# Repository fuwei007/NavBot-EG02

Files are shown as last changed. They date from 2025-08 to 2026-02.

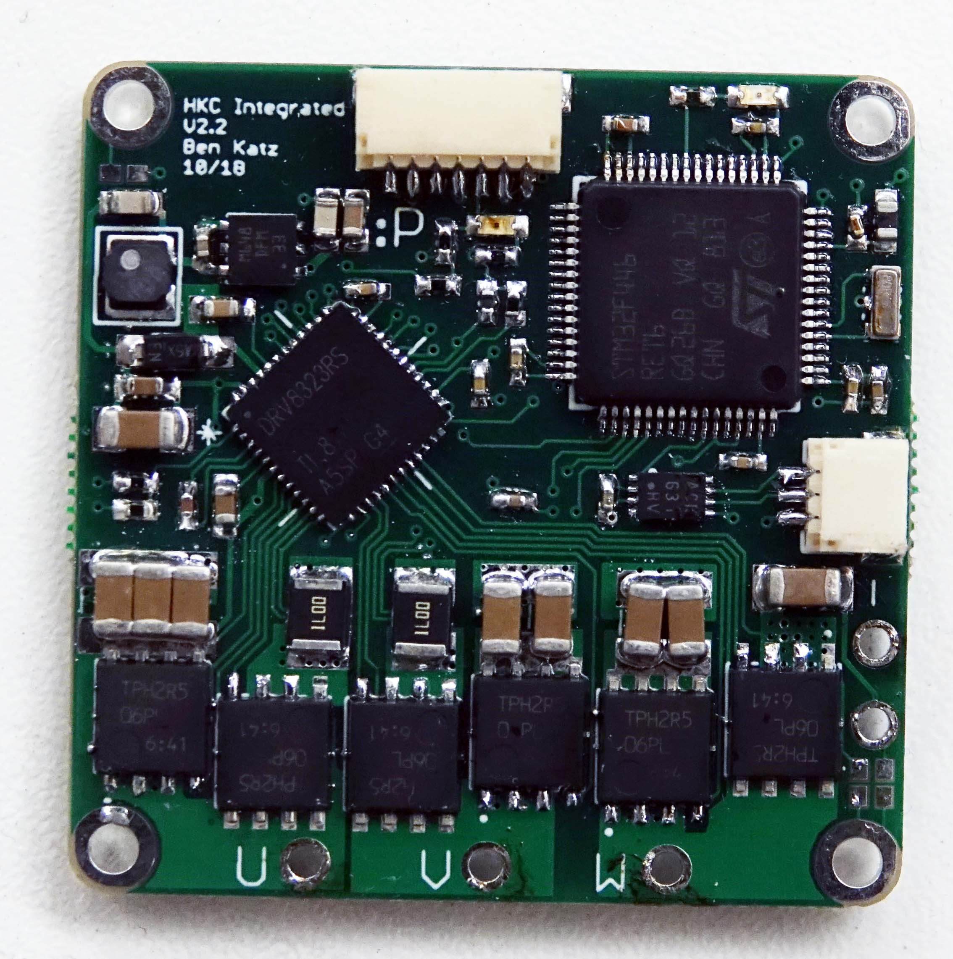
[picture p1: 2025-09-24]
2-Hardware/3phase_integrated-master/New Version/Cheetah Driver Integrated V4 connector/photos/DSC01706.JPG

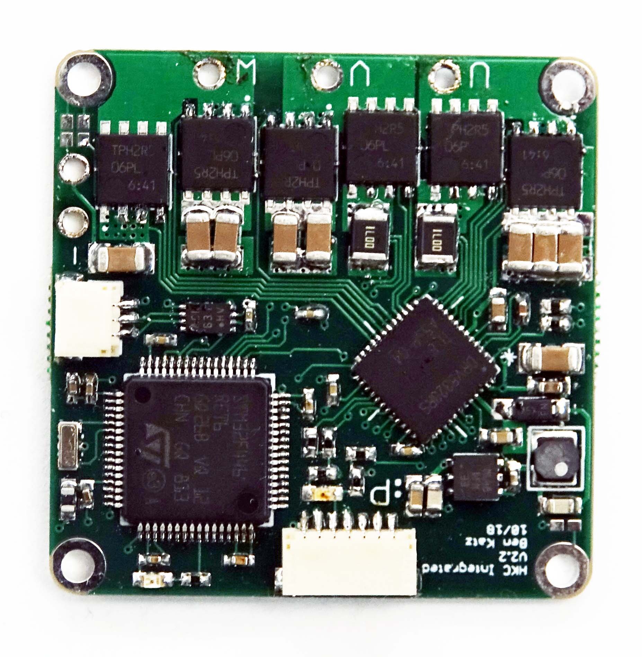
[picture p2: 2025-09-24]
2-Hardware/3phase_integrated-master/New Version/Cheetah Driver Integrated V4 connector/photos/DSC01701.JPG

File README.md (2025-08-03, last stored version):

# Mini Cheetah Single Leg Dev Kit (EG02)

This repository contains all open-source hardware and software resources to replicate and extend a **single leg of the MIT Mini Cheetah** robot. The goal is to provide a modular, low-cost, and extensible robotic leg development kit.

## ✅ Project Highlights
- Jetson Orin Nano 8GB as main controller
- MN5212 BLDC motor + NEMA 23 planetary gearbox + AS5047P magnetic encoder
- FSESC6.7 70A single-channel VESC motor driver
- Open-source mechanical parts (encoder mount, couplers) and ROS2-compatible design

## 📦 Current Progress
- [x] Hardware sourcing ✅
- [x] Encoder mount printed ✅
- [ ] Wiring & configuration in progress 🔧
- [ ] Jetson control code WIP 💻
- [ ] Quadruped-ready architecture in design 🐾

## 📁 Folder Structure
- `/hardware/` 3D models, CAD drawings, and mechanical designs
- `/jetson_control/` Jetson-side control scripts and ROS2 nodes
- `/docs/` BOM, wiring diagrams, setup notes
- `/config/` VESC settings, encoder calibration files

## 📷 Project Images
(To be added in `/images/`)

## 📜 License
MIT License

---
Project initiated by **NavBot LLC**. Contributions welcome!

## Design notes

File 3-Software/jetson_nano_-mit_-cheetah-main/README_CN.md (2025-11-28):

# MIT Mini Cheetah Software (自制硬件适配版)

本项目是 MIT Mini Cheetah 软件仓库的自制硬件适配版本。以下文档记录了编译、配置及针对自制硬件（Wheeltec IMU、自制腿部结构、Logitech F710 手柄）的详细调试与适配过程。

## 1. 编译与运行指南

### 1.1 命令行编译
建议在项目根目录下的 `mc-build` 文件夹中进行构建。

```bash
cd mc-build
rm CMakeCache.txt  # 清理旧配置（如有必要）

# 配置项目
# -DMINI_CHEETAH_BUILD=TRUE: 构建 Mini Cheetah 版本
# -DJCQP_USE_AVX2=OFF: 关闭 x86 AVX2 优化，适配 ARM 架构（如 Jetson Nano/NX）
cmake -DMINI_CHEETAH_BUILD=TRUE -DJCQP_USE_AVX2=OFF ..

# 编译（根据 CPU 核心数调整 -j 参数）
make -j4
```

### 1.2 运行控制器
生成的控制器位于 `user/MIT_Controller` 目录下。需要使用 `sudo` 权限运行以访问硬件端口。

*   **真机模式**：
    ```bash
    sudo ./user/MIT_Controller/mit_ctrl m r f
    ```
*   **仿真模式**：
    ```bash
    sudo ./user/MIT_Controller/mit_ctrl m s
    ```

---

## 2. 开发环境配置 (VSCode Remote - SSH)

推荐使用 VSCode 进行远程开发与调试。

1.  本机安装 **Remote - SSH** 与 **CMake Tools** 扩展。
2.  通过 Remote-SSH 连接到目标主机（如 Jetson），打开项目目录。
3.  项目已预置 `.vscode/settings.json`，自动配置构建参数。
4.  **首次使用**：
    *   按 `F1` 或 `Ctrl+Shift+P`，输入 `CMake: Select Kit`，选择远程环境的编译器（如 `GCC for arm64`）。
    *   确保 `mc-build` 目录存在。
5.  **一键编译**：
    *   点击 VSCode 底部状态栏的 **Build** 按钮即可触发远程编译。
    *   如需清理缓存，使用命令 `CMake: Delete Cache and Reconfigure`。

**`.vscode/settings.json` 参考配置：**
```jsonc
{
  "cmake.buildDirectory": "${workspaceFolder}/mc-build",
  "cmake.generator": "Unix Makefiles",
  "cmake.configureArgs": [
    "-DMINI_CHEETAH_BUILD=TRUE",
    "-DJCQP_USE_AVX2=OFF"
  ],
  "cmake.buildArgs": [
    "-j4"
  ]
}
```

---

## 3. 硬件配置说明

*   **IMU**: 默认适配 **Wheeltec H30** 惯导模块。
    *   可通过环境变量调整串口：
        *   `H30_IMU_PORT` (默认 `/dev/ttyACM0`)
        *   `H30_IMU_BAUD` (默认 `460800`)
*   **遥控器**: 适配 **Logitech F710** 无线手柄。
    *   手柄必须拨至 **D (DirectInput)** 模式。
    *   默认设备路径：`/dev/input/js0` (可通过 `F710_DEVICE` 环境变量修改)。
    *   程序强制 `use_rc=0`，无需连接 SBUS 接收机。

---

## 4. 自制硬件适配与调试记录 (2025-11)

### 4.1 核心问题解决：自旋与侧翻
在调试初期，机器人进入 `BalanceStand` 后会出现剧烈的自旋（Yaw 轴）或侧翻（Roll 轴）。

*   **原因**：Wheeltec H30 IMU 的 Roll/Pitch/Yaw 三轴数据方向与 MIT 控制器预期**完全相反**。导致控制器输出的正反馈力矩加剧了失稳。
    *   现象：左转 Yaw 减小（应增加），右倾 Roll 减小（应增加），抬头 Pitch 增加（MIT 定义低头为正）。
*   **修复**：修改 `third-party/wheeltec_imu/WheeltecImu.cpp` 中的 `handlePacket` 函数。
    *   **操作**：将四元数转换为 RPY 欧拉角，**对 Roll, Pitch, Yaw 三轴全部取反**，再转回四元数。
    *   **结果**：姿态估计正确，`BalanceStand` 立即稳定。

### 4.2 动力学模型修正
*   **文件**：`common/include/Dynamics/MiniCheetah.h`
*   **腿部惯量**：自制腿部较重。尝试过放大惯量 (`inertia_scale = 2.0`)，但导致控制过激。最终**回调至 1.0** (MIT 原版参数)，配合增益调整效果最佳。
*   **机身惯量**：将人为放大的 `bodyRotationalInertia` 从 3.0 倍回调至 **1.5 倍**，使模型更接近物理真实。

### 4.3 底层驱动校准
*   **文件**：`robot/src/rt/rt_spi.cpp`
*   **电机零位**：硬编码的 `abad/hip/knee_offset` 是底层物理零位，必须严格对应电机编码器的几何零点。
*   **电机方向**：验证了 `*_side_sign` 数组。确认左后腿 (Leg 3) Abad 向外摆动时读数增加（正），符合 MIT 定义。

### 4.4 控制参数调优
*   **文件**：`config/mc-mit-ctrl-user-parameters.yaml`
*   **解决“趴得低”**：
    *   增加 Z 轴位置刚度 `Kp_body[2]`：从 60 提高到 **100**。
*   **解决“Hip 软 / 前后晃”**：
    *   增加关节位置刚度 `Kp_joint`：从 `[6, 6, 6]` 调整为 **`[6, 8, 8]`** (Abad, Hip, Knee)。
    *   增加关节阻尼 `Kd_joint`：从 `[0.4, 0.4, 0.4]` 调整为 **`[0.4, 0.8, 0.8]`**。
*   **解决“劈叉”**：
    *   主要依赖增加 Abad 关节刚度（如上所述）。
    *   如有需要，可降低 `RPC_mu` (摩擦系数) 来限制侧向力。

### 4.5 手柄控制功能实现
MIT 原始代码未将 Gamepad 数据映射到核心控制指令 `rcCommand`，导致手柄摇杆无效。

*   **修复**：在 `robot/src/RobotRunner.cpp` 的 `run()` 函数中（`setupStep()` 调用**之后**）添加映射逻辑。
*   **映射关系 (符合 MIT 习惯)**：
    *   **右摇杆**：控制 Roll (左右倾斜) / Pitch (前后倾斜)。
    *   **左摇杆**：控制 Yaw (转向，需取反 `-LX`) / Height (高度升降)。
*   **灵敏度**：设置缩放系数 `kScaleRPY = 0.35`, `kScaleH = 0.4`，手感柔和。
*   **控制模式**：`FSM_State_BalanceStand.cpp` 修改为**松手自动回中**（比例控制），松开摇杆后机器人自动恢复水平和初始高度。

### 4.6 遗留风险提示
*   **Locomotion (原地踏步)**：**极高风险！**
    *   目前的接触估计器 (`ContactEstimator`) 是基于步态计划的盲信逻辑，不依赖真实触地反馈。
    *   **未验证项**：IMU 的线性加速度 (Acc) 方向尚未经过严格验证（虽然 RPY 已修）。如果 Acc 方向也是反的，卡尔曼滤波会瞬间发散导致炸机。
    *   **建议**：在严格验证 Acc 方向（前推 AccX 为正，静止 Z 为 +9.8）之前，**严禁尝试 Trot 步态**。

---

## 常用 Git 命令速查

### 本地操作
*   **补充提交**（修改上一次 commit）：
    ```bash
    git commit --amend --no-edit
    ```
*   **强制推送**（覆盖远端）：
    ```bash
    git push --force-with-lease
    ```

### 远程同步
*   **强制重置到远端 main**（丢弃本地所有修改）：
    ```bash
    git fetch origin && git reset --hard origin/main && git clean -fd
    ```
    *   `git fetch origin`: 获取最新元数据
    *   `git reset --hard origin/main`: 强制移动指针并重置工作区
    *   `git clean -fd`: 删除未跟踪的文件和目录

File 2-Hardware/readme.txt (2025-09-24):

主要是电路板和底层软件： MIT Cheetah Mini 电机驱动器, 连接12个电机与机载电脑的中心板(SPIne)的代码和硬件

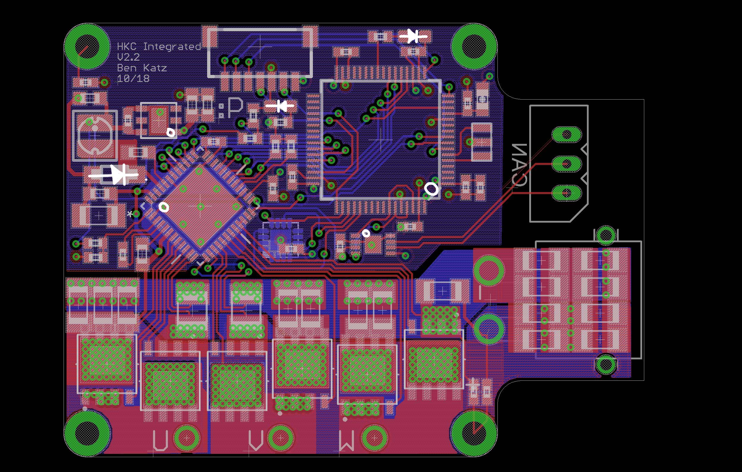
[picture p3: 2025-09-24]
2-Hardware/3phase_integrated-master/New Version/Cheetah Driver Integrated V4 connector/board.JPG

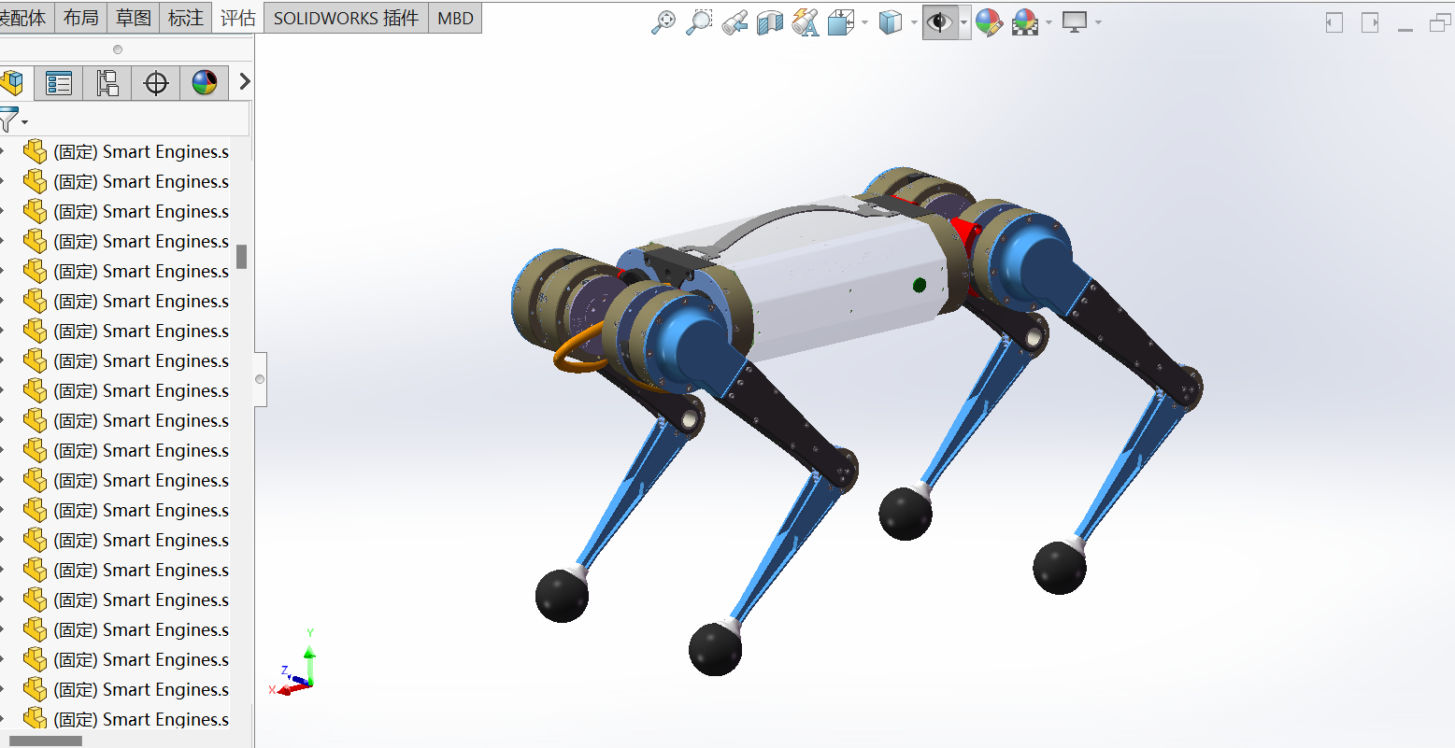
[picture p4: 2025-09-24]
1-3D Files/sw.png

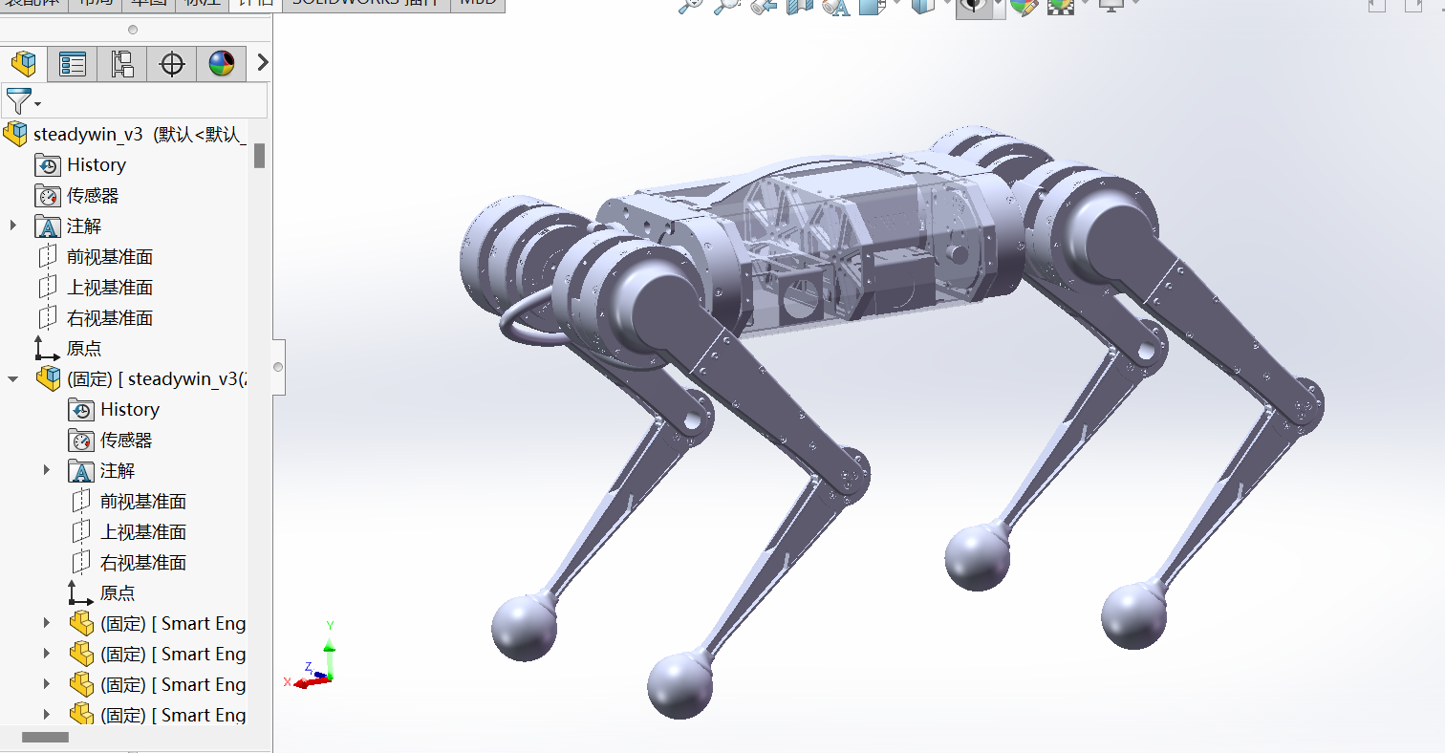
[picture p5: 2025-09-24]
1-3D Files/structure.png

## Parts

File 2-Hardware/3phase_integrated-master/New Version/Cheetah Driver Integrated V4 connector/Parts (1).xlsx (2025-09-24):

Supplied Parts
Qty Per Board | Value | Device | Package | Parts | MFG Part | 56
1 | DRV8323RH | DRV8323RH | QFN50P700X700X90-49N | U$1 | ‎DRV8323RSRGZT‎
2 | G | LED0603 | LED-0603 | LED1, LED2 | LTST-C191KRKT‎
1 | 3.3V 500 mA LDO | LDFM | DFN6-3X3 | LDFM33PUR | ‎LDFM33PUR‎
1 | MA700 | MA700 | QFN16 | U$11 | ‎MA700GQ-Z‎
1 | MCP2542 | MCP2542 | TDFN | U$6 | ‎MCP2542FDT-H/MNY‎
1 | SM07B-SRSS-TB | SM07B-SRSS-TB | SM07B-SRSS-TB | PROG | ‎SM07B-SRSS-TB(LF)(SN)‎
1 | STM32F446RET6 | STM32F446RET6 | TQFP64 | U$3 | ‎STM32F446RET6‎
6 | 60V | MOSFET | Power SO8 | Q1, Q2, Q3, Q4, Q5, Q6 | ‎TPH2R506PL,L1Q‎
9 | 10 uF 50v | C-USC1206K | C1206K | C1, C8, C11, C12, C13, C14, C15, C16, C17, C21, C22, C23, C24, C25, C26, C28, C29 | GRT31CR61H106ME01L
1 | 22uH 500 mA | SDR0302 | SDR0302 | L1 | ‎NRH3012T220MN‎
2 | 0.001 | R-US_R1210 | R1210 | R6, R7 | ‎PMR25HZPFV1L00‎
1 | 600r | INDUCTOR0603 | 603 | CHOKE | ‎PE-0603FB601ST‎
1 | 8 Mhz Ceramic Resonator | CSTCE | CSTCE | XT1 | ‎CSTNE8M00GH5L000R0‎
1 | 500 mA 60v | DIODE-SOD123 | SOD123 | D1 | ‎MBR0580S1-7‎
8 | .1 uF 10v X5R/X7R | C-USC0402K | C0402K | C18, C27, C31, C32, C33, C34, C41, VREFCAP | ‎CL05A104MP5NNNC
2 | .1 uF 50v X5R/X7R | C-USC0603K | C0603K | C2, C4 | ‎CC0603JRX7R9BB104‎
3 | 1 uF 10v X5R/X7R | C-USC0402K | C0402K | C7, C10, MC1 | ‎CL05A105MP5NNNC‎
1 | 1 uF 50v X5R/X7R | C-USC0603K | C0603K | C6 | ‎CL10A105KB8NNNC‎
4 | 10k 1% | R-US_R0402 | R0402 | R2, R3, R4 R27 | ‎RT0402DRE0710KL‎
1 | 150k 1% | R-US_R0402 | R0402 | R26 | ‎RMCF0402FT150K‎
2 | 200 5% | R-US_R0402 | R0402 | R5, R22 | ‎RC0402JR-07200RL‎
3 | 22 uF 10v X5R/X7R | C-USC0603K | C0603K | C3, C19, C20 | ‎CL10A226MPCNUBE‎
1 | 4.7 uF 10v X5R/X7R | C-USC0402K | C0402K | C9 | ‎GRM155R60J475ME87D‎
1 | 47 nF 50v X5R/X7R | C-USC0402K | C0402K | C5 | ‎CGA2B3X7R1H473M050BD‎
1 | 54.9k 1% | R-US_R0402 | R0402 | R1 | ‎RC0402FR-0754K9L‎

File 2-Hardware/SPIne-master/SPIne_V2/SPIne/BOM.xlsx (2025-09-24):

Qty | Value | Package | Part | MFG Part Number | Digikey Number
1 |  | 43045-0400 | DC_IN | ‎0430450400‎ | ‎WM1814-ND‎
1 |  | MA20-1L | SV1 | ‎M20-7822046‎ | ‎952-1905-ND‎
4 | 120 | R0402 | R3, R5, R6, R7 | ‎CRGCQ0603F120R‎ | ‎A129677CT-ND‎
1 | DNP | R0402 | BYP
20 | .1 uF | C0603K | C1, C8, C12, C14, C16, C18, C19, C20, C21, C22, C23, C24, C4, C5, C6, C25, C27, C29, C31, C32 | ‎C0603C104M5RACTU‎ | ‎399-7845-1-ND‎
8 | 1uF | C0603 | C7, C41, C11, C13, C15, C17, C3, C10 | ‎UMK107AB7105KA-T‎ | ‎587-3247-1-ND‎
1 | 10 uF | C0805K | C30 | ‎GRM188R61E106MA73D‎ | ‎490-7202-1-ND‎
2 | 4.7 uF | C0603 | C2, C9 | ‎CL10A475MQ8NNNC‎ | ‎1276-1907-1-ND‎
5 | 47 uF | C1206K | C28, C33, C34, C35, C36 | ‎GRM32EC81C476KE15K‎ | ‎490-16309-1-ND‎
2 | 600r | 603 | CHOKE, CHOKE1 | ‎PE-0603FB601ST‎ | ‎553-2384-1-ND‎
2 | 200 | R0603 | R4, R22 | ‎RC0603JR-07200RL‎ | ‎311-200GRCT-ND‎
1 | 74AHC1G14DCK | SC70-5 | IC1 | SN74AHC1G14DCKR | 296-8748-1-ND
2 | BM07B-SRSS-TB | BM07B-SRSS-TB | PROG, PROG1 | ‎BM07B-SRSS-TB(LF)(SN)‎ | ‎455-1793-1-ND‎
2 | CSTCE | CSTCE | XT1, XT2 | CSTNE8M00GH5C000R0‎ | ‎490-17961-1-ND‎
2 | LED_RED | LED-0603 | LED2, LED4 | ‎LTST-C191KRKT‎ | ‎160-1447-1-ND‎
1 | LM1117 | SOT-223 | VR1 | LM1117MPX-3.3/NOPB | LM1117MPX-3.3/NOPBCT-ND
4 | ‎MCP2562-E/SN‎ | SO08 | U$4, U$5, U$6, U$7 | ‎MCP2562-E/SN‎ | ‎MCP2562-E/SN-ND‎
4 | SI8621EC-B-IS | SO08 | U$8, U$9, U$10, U$11 | SI8621EC-B-IS | 336-2066-5-ND
2 | STM32F446RET6 | TQFP64 | U$1, U$3 | ‎STM32F446RET6‎ | ‎497-15376-ND‎
4 | ‎CRE1S0505S3C‎ | 4SIL | DC1, DC2, DC3, DC4 | ‎CRE1S0505S3C‎ | ‎811-3195-ND‎
4 | 17mm hex standoff |  |  | ‎971170151‎ | ‎732-10424-ND‎
4 | 11mm hex standoff |  |  | ‎M2106-2545-AL‎ | ‎1772-2024-ND‎
1 | 40 pin |  |  | SSQ-120-02-T-D | SAM1193-20-ND

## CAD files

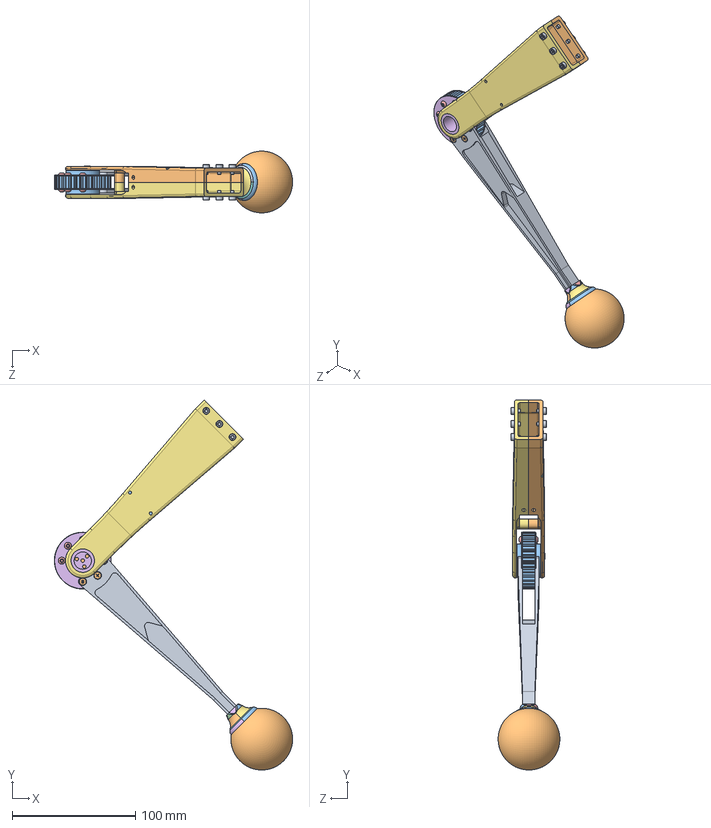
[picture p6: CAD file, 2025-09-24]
1-3D Files/sw2022/MIT-机器狗-腿部结构.SLDASM
193.0 x 299.7 x 50.0 mm
Smart Engines.sldasm-Part-32
Smart Engines.sldasm-Part-33
Smart Engines.sldasm-Part-34 x 15
Smart Engines.sldasm-Part-35
Smart Engines.sldasm-Part-36
Smart Engines.sldasm-Part-37
Smart Engines.sldasm-Part-38
Smart Engines.sldasm-Part-39
Smart Engines.sldasm-Part-40
Smart Engines.sldasm-Part-41
Smart Engines.sldasm-Part-42
Smart Engines.sldasm-Part-43
Smart Engines.sldasm-Part-44
Smart Engines.sldasm-Part-45
Smart Engines.sldasm-Part-46
Smart Engines.sldasm-Part-47
Smart Engines.sldasm-Part-48
Smart Engines.sldasm-Part-49
Smart Engines.sldasm-Part-50
Smart Engines.sldasm-Part-51
Smart Engines.sldasm-Part-52
Smart Engines.sldasm-Part-53
Smart Engines.sldasm-Part-54
Smart Engines.sldasm-Part-55
Smart Engines.sldasm-Part-56
Smart Engines.sldasm-Part-57
Smart Engines.sldasm-Part-58
Smart Engines.sldasm-Part-59
Smart Engines.sldasm-Part-60
Smart Engines.sldasm-Part-61
Smart Engines.sldasm-Part-62
Smart Engines.sldasm-Part-63
Smart Engines.sldasm-Part-64
Smart Engines.sldasm-Part-65
Smart Engines.sldasm-Part-66
Smart Engines.sldasm-Part-67
Smart Engines.sldasm-Part-68
Smart Engines.sldasm-Part-69
Smart Engines.sldasm-Part-70
Smart Engines.sldasm-Part-71
Smart Engines.sldasm-Part-72
Smart Engines.sldasm-Part-73
Smart Engines.sldasm-Part-74
Smart Engines.sldasm-Part-75
Smart Engines.sldasm-Part-76
Smart Engines.sldasm-Part-77
Smart Engines.sldasm-Part-78
Smart Engines.sldasm-Part-79
Smart Engines.sldasm-Part-80
Smart Engines.sldasm-Part-81
Smart Engines.sldasm-Part-82
Smart Engines.sldasm-Part-83
Smart Engines.sldasm-Part-84
Smart Engines.sldasm-Part-85
Smart Engines.sldasm-Part-86
Smart Engines.sldasm-Part-87
Smart Engines.sldasm-Part-88 x 6
Smart Engines.sldasm-Part-90 x 9
Smart Engines.sldasm-Part-91 x 2
Smart Engines.sldasm-Part-92 x 3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

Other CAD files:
1-3D Files/sw2022/Smart Engines.sldasm-Part-90.SLDPRT
1-3D Files/sw2022/Smart Engines.sldasm-Part-38.SLDPRT
1-3D Files/sw2022/Smart Engines.sldasm-Part-66.SLDPRT
1-3D Files/sw2022/Smart Engines.sldasm-Part-40.SLDPRT
1-3D Files/sw2022/Smart Engines.sldasm-Part-121.SLDPRT
1-3D Files/sw2022/Smart Engines.sldasm-Part-2.SLDPRT
1-3D Files/sw2022/Smart Engines.sldasm-Part-82.SLDPRT
1-3D Files/sw2022/Smart Engines.sldasm-Part-68.SLDPRT
1-3D Files/sw2022/Smart Engines.sldasm-Part-37.SLDPRT
1-3D Files/sw2022/Smart Engines.sldasm-Part-3.SLDPRT
1-3D Files/sw2022/Smart Engines.sldasm-Part-43.SLDPRT
1-3D Files/sw2022/Smart Engines.sldasm-Part-64.SLDPRT
1-3D Files/sw2022/Smart Engines.sldasm-Part-84.SLDPRT
1-3D Files/sw2022/Smart Engines.sldasm-Part-72.SLDPRT
1-3D Files/sw2022/Smart Engines.sldasm-Part-101.SLDPRT
1-3D Files/sw2022/Smart Engines.sldasm-Part-108.SLDPRT
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

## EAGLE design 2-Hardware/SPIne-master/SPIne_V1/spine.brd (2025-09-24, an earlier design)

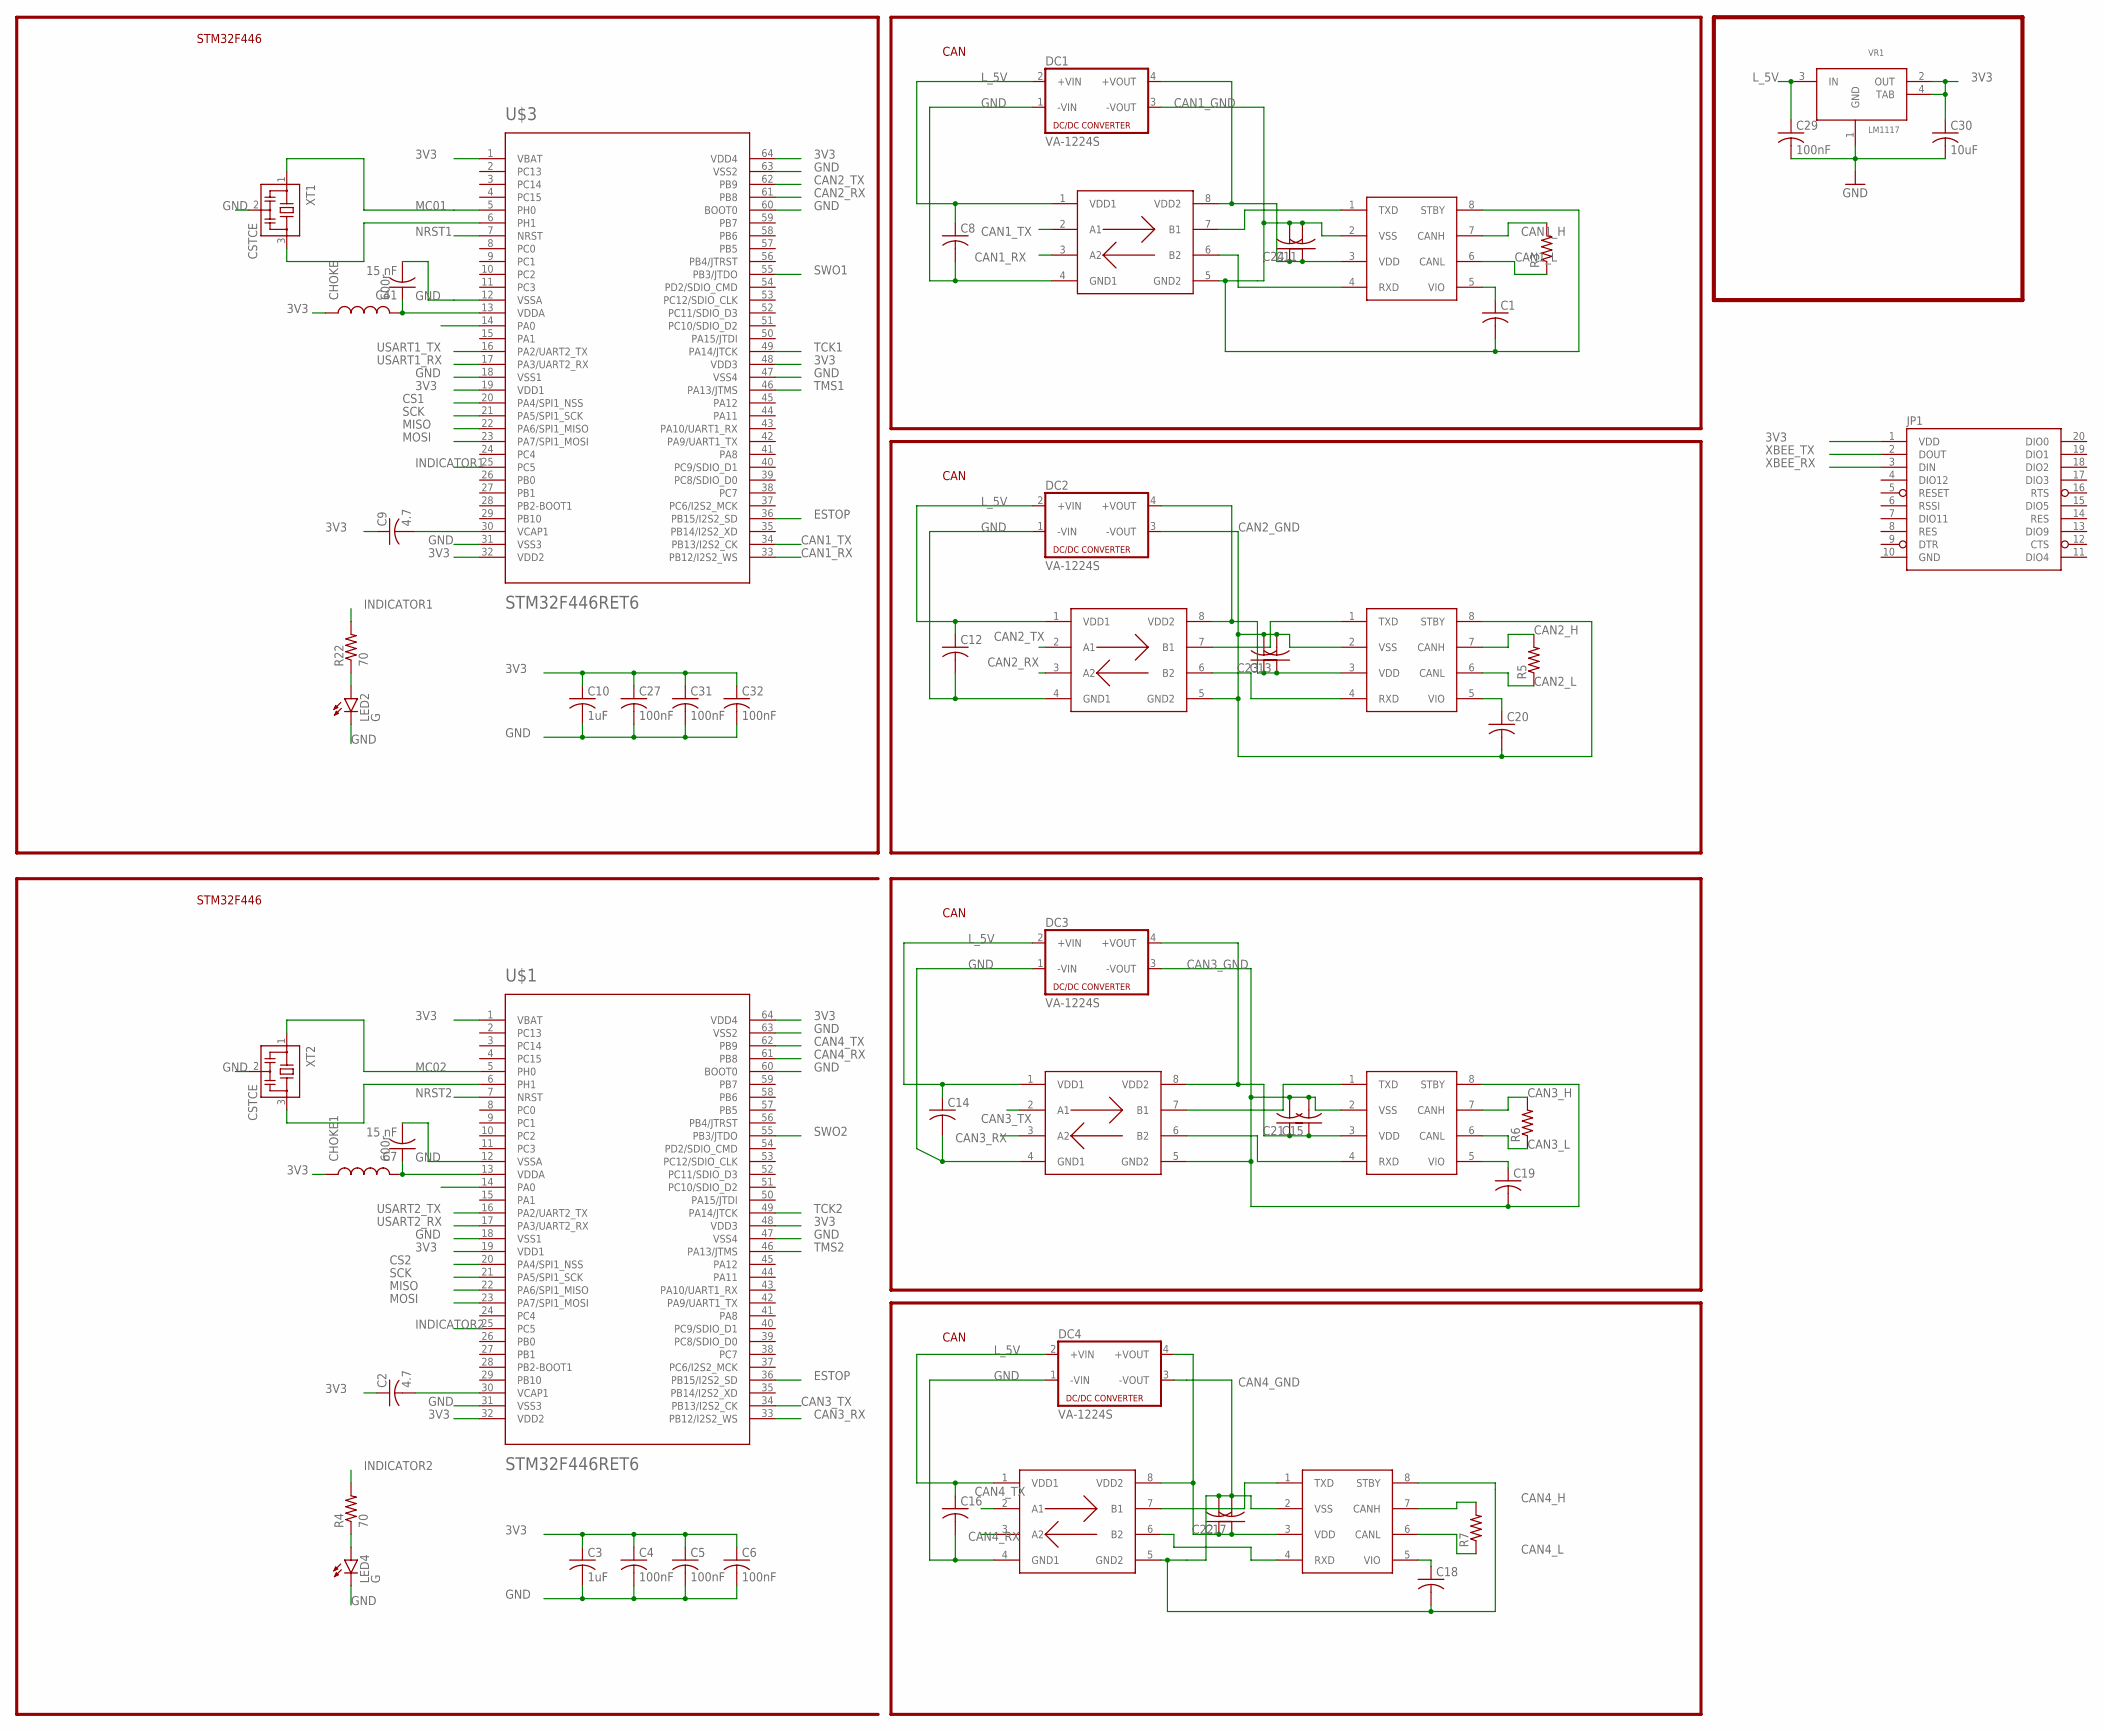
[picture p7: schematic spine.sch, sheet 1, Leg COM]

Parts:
C1, C8, C11, C12, C13, C14, C15, C16, C17, C18, C19, C20, C21, C22, C23, C24: C-USC0603K; C0603K
C2, C9: 4.7; C0603
C3, C10: 1uF; C0603
C4, C5, C6, C27, C29, C31, C32: 100nF; C0603
C7, C41: 15 nF; C0603
C30: 10uF; C0805K
CHOKE, CHOKE1: 600r; 0603
DC1, DC2, DC3, DC4: VA-1224S; 4SIL
JP1: XBEE-1B1; XBEE-1
LED2, LED4: G; LED-0603
R3, R5, R6, R7: R-US_R0603; R0603
R4, R22: 70; R0603
U$1, U$3: STM32F446RET6; TQFP64
U$4, U$5, U$6, U$7: MCP2561; SO08
U$8, U$9, U$10, U$11: SI8410; SO08
VR1: LM1117; SOT-223
XT1, XT2: CSTCE

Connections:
3V3: C2.1, C3.1, C4.1, C5.1, C6.1, C9.1, C10.1, C27.1, C30.1, C31.1, C32.1, CHOKE.1, CHOKE1.1, JP1.1 (VDD), U$1.1 (VBAT), U$1.19 (VDD1), U$1.32 (VDD2), U$1.48 (VDD3), U$1.64 (VDD4), U$3.1 (VBAT), U$3.19 (VDD1), U$3.32 (VDD2), U$3.48 (VDD3), U$3.64 (VDD4), VR1.2 (OUT), VR1.4 (TAB); also elsewhere on the board
CAN1_GND: C1.2, C11.2, C24.2, DC1.3 (-VOUT), U$4.2 (VSS), U$4.8 (STBY), U$8.5 (GND2); also elsewhere on the board
CAN1_H: R3.2, U$4.7 (CANH); also elsewhere on the board
CAN1_L: R3.1, U$4.6 (CANL); also elsewhere on the board
CAN1_RX: U$3.33 (PB12/I2S2_WS), U$8.3 (A2)
CAN1_TX: U$3.34 (PB13/I2S2_CK), U$8.2 (A1)
CAN2_GND: C13.2, C20.2, C23.2, DC2.3 (-VOUT), U$5.2 (VSS), U$5.8 (STBY), U$10.5 (GND2); also elsewhere on the board
CAN2_H: R5.2, U$5.7 (CANH); also elsewhere on the board
CAN2_L: R5.1, U$5.6 (CANL); also elsewhere on the board
CAN2_RX: U$3.61 (PB8), U$10.3 (A2)
CAN2_TX: U$3.62 (PB9), U$10.2 (A1)
CAN3_GND: C15.2, C19.2, C21.2, DC3.3 (-VOUT), U$6.2 (VSS), U$6.8 (STBY), U$9.5 (GND2); also elsewhere on the board
CAN3_H: R6.2, U$6.7 (CANH); also elsewhere on the board
CAN3_L: R6.1, U$6.6 (CANL); also elsewhere on the board
CAN3_RX: U$1.33 (PB12/I2S2_WS), U$9.3 (A2)
CAN3_TX: U$1.34 (PB13/I2S2_CK), U$9.2 (A1)
CAN4_GND: C17.2, C18.2, C22.2, DC4.3 (-VOUT), U$7.2 (VSS), U$7.8 (STBY), U$11.5 (GND2); also elsewhere on the board
CAN4_H: R7.2, U$7.7 (CANH); also elsewhere on the board
CAN4_L: R7.1, U$7.6 (CANL); also elsewhere on the board
CAN4_RX: U$1.61 (PB8), U$11.3 (A2)
CAN4_TX: U$1.62 (PB9), U$11.2 (A1)
CS1: U$3.20 (PA4/SPI1_NSS); also elsewhere on the board
CS2: U$1.20 (PA4/SPI1_NSS); also elsewhere on the board
ESTOP: U$1.36 (PB15/I2S2_SD), U$3.36 (PB15/I2S2_SD); also elsewhere on the board
GND: C3.2, C4.2, C5.2, C6.2, C7.2, C8.2, C10.2, C12.2, C14.2, C16.2, C27.2, C29.2, C30.2, C31.2, C32.2, C41.2, DC1.1 (-VIN), DC2.1 (-VIN), DC3.1 (-VIN), DC4.1 (-VIN), JP1.10 (GND), LED2.C, LED4.C, U$1.12 (VSSA), U$1.18 (VSS1), U$1.31 (VSS3), U$1.47 (VSS4), U$1.60 (BOOT0), U$1.63 (VSS2), U$3.12 (VSSA), U$3.18 (VSS1), U$3.31 (VSS3), U$3.47 (VSS4), U$3.60 (BOOT0), U$3.63 (VSS2), U$8.4 (GND1), U$9.4 (GND1), U$10.4 (GND1), U$11.4 (GND1), VR1.1 (GND), XT1.2, XT2.2; also elsewhere on the board
INDICATOR1: R22.2, U$3.25 (PC5)
INDICATOR2: R4.2, U$1.25 (PC5)
L_5V: C8.1, C12.1, C14.1, C16.1, C29.1, DC1.2 (+VIN), DC2.2 (+VIN), DC3.2 (+VIN), DC4.2 (+VIN), U$8.1 (VDD1), U$9.1 (VDD1), U$10.1 (VDD1), U$11.1 (VDD1), VR1.3 (IN); also elsewhere on the board
MC01: U$3.5 (PH0), XT1.1
MC02: U$1.5 (PH0), XT2.1
MISO: U$1.22 (PA6/SPI1_MISO), U$3.22 (PA6/SPI1_MISO); also elsewhere on the board
MOSI: U$1.23 (PA7/SPI1_MOSI), U$3.23 (PA7/SPI1_MOSI); also elsewhere on the board
unnamed: C41.1, CHOKE.2, U$3.13 (VDDA)
unnamed: C9.2, U$3.30 (VCAP1)
unnamed: C7.1, CHOKE1.2, U$1.13 (VDDA)
unnamed: C2.2, U$1.30 (VCAP1)
unnamed: C1.1, U$4.5 (VIO)
unnamed: LED4.A, R4.1
unnamed: U$1.6 (PH1), XT2.3
unnamed: C17.1, C22.1, DC4.4 (+VOUT), U$7.3 (VDD), U$11.8 (VDD2)
unnamed: C20.1, U$5.5 (VIO)
unnamed: C15.1, C21.1, DC3.4 (+VOUT), U$6.3 (VDD), U$9.8 (VDD2)
unnamed: C11.1, C24.1, DC1.4 (+VOUT), U$4.3 (VDD), U$8.8 (VDD2)
unnamed: U$4.1 (TXD), U$8.7 (B1)
unnamed: U$7.1 (TXD), U$11.7 (B1)
unnamed: U$4.4 (RXD), U$8.6 (B2)
unnamed: U$7.4 (RXD), U$11.6 (B2)
unnamed: C18.1, U$7.5 (VIO)
unnamed: C13.1, C23.1, DC2.4 (+VOUT), U$5.3 (VDD), U$10.8 (VDD2)
unnamed: U$5.1 (TXD), U$10.7 (B1)
unnamed: U$5.4 (RXD), U$10.6 (B2)
unnamed: C19.1, U$6.5 (VIO)
unnamed: U$6.1 (TXD), U$9.7 (B1)
unnamed: U$6.4 (RXD), U$9.6 (B2)
unnamed: LED2.A, R22.1
unnamed: U$3.6 (PH1), XT1.3
NRST1: U$3.7 (NRST); also elsewhere on the board
NRST2: U$1.7 (NRST); also elsewhere on the board
SCK: U$1.21 (PA5/SPI1_SCK), U$3.21 (PA5/SPI1_SCK); also elsewhere on the board
SWO1: U$3.55 (PB3/JTDO); also elsewhere on the board
SWO2: U$1.55 (PB3/JTDO); also elsewhere on the board
TCK1: U$3.49 (PA14/JTCK); also elsewhere on the board
TCK2: U$1.49 (PA14/JTCK); also elsewhere on the board
TMS1: U$3.46 (PA13/JTMS); also elsewhere on the board
TMS2: U$1.46 (PA13/JTMS); also elsewhere on the board
USART1_RX: U$3.17 (PA3/UART2_RX); also elsewhere on the board
USART1_TX: U$3.16 (PA2/UART2_TX); also elsewhere on the board
USART2_RX: U$1.17 (PA3/UART2_RX); also elsewhere on the board
USART2_TX: U$1.16 (PA2/UART2_TX); also elsewhere on the board
XBEE_RX: JP1.3 (DIN); also elsewhere on the board
XBEE_TX: JP1.2 (DOUT); also elsewhere on the board

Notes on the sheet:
STM32F446
CAN

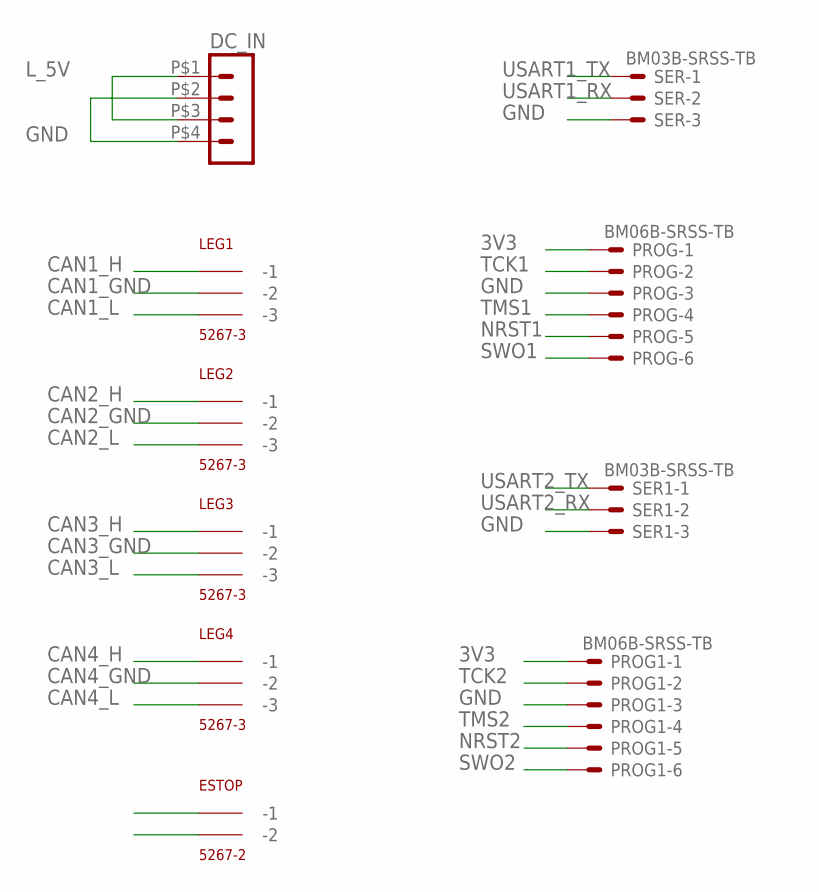
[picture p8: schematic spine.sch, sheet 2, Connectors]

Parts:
DC_IN: HEADER_POS4_43045-0401; 43045-0400
ESTOP: 5267-2
LEG1, LEG2, LEG3, LEG4: 5267-3
PROG, PROG1: BM06B-SRSS-TB
SER, SER1: BM03B-SRSS-TB

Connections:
3V3: PROG.1, PROG1.1; also elsewhere on the board
CAN1_GND: LEG1.P$2 (-2); also elsewhere on the board
CAN1_H: LEG1.P$1 (-1); also elsewhere on the board
CAN1_L: LEG1.P$3 (-3); also elsewhere on the board
CAN2_GND: LEG2.P$2 (-2); also elsewhere on the board
CAN2_H: LEG2.P$1 (-1); also elsewhere on the board
CAN2_L: LEG2.P$3 (-3); also elsewhere on the board
CAN3_GND: LEG3.P$2 (-2); also elsewhere on the board
CAN3_H: LEG3.P$1 (-1); also elsewhere on the board
CAN3_L: LEG3.P$3 (-3); also elsewhere on the board
CAN4_GND: LEG4.P$2 (-2); also elsewhere on the board
CAN4_H: LEG4.P$1 (-1); also elsewhere on the board
CAN4_L: LEG4.P$3 (-3); also elsewhere on the board
ESTOP: ESTOP.P$2 (-2); also elsewhere on the board
GND: DC_IN.P$2 (2), DC_IN.P$4 (4), ESTOP.P$1 (-1), PROG.3, PROG1.3, SER.3, SER1.3; also elsewhere on the board
L_5V: DC_IN.P$1 (1), DC_IN.P$3 (3); also elsewhere on the board
NRST1: PROG.5; also elsewhere on the board
NRST2: PROG1.5; also elsewhere on the board
SWO1: PROG.6; also elsewhere on the board
SWO2: PROG1.6; also elsewhere on the board
TCK1: PROG.2; also elsewhere on the board
TCK2: PROG1.2; also elsewhere on the board
TMS1: PROG.4; also elsewhere on the board
TMS2: PROG1.4; also elsewhere on the board
USART1_RX: SER.2; also elsewhere on the board
USART1_TX: SER.1; also elsewhere on the board
USART2_RX: SER1.2; also elsewhere on the board
USART2_TX: SER1.1; also elsewhere on the board

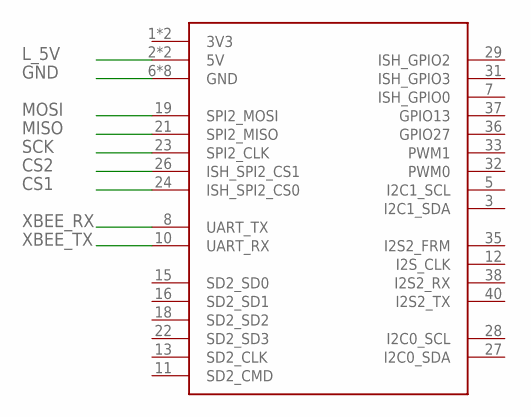
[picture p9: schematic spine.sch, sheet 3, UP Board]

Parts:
U$2: UP_BOARD

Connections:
CS1: U$2.24 (ISH_SPI2_CS0); also elsewhere on the board
CS2: U$2.26 (ISH_SPI2_CS1); also elsewhere on the board
GND: U$2.6 (GND), U$2.9 (GND), U$2.14 (GND), U$2.20 (GND), U$2.25 (GND), U$2.30 (GND), U$2.34 (GND), U$2.39 (GND); also elsewhere on the board
L_5V: U$2.2 (5V), U$2.4 (5V); also elsewhere on the board
MISO: U$2.21 (SPI2_MISO); also elsewhere on the board
MOSI: U$2.19 (SPI2_MOSI); also elsewhere on the board
SCK: U$2.23 (SPI2_CLK); also elsewhere on the board
XBEE_RX: U$2.8 (UART_TX); also elsewhere on the board
XBEE_TX: U$2.10 (UART_RX); also elsewhere on the board

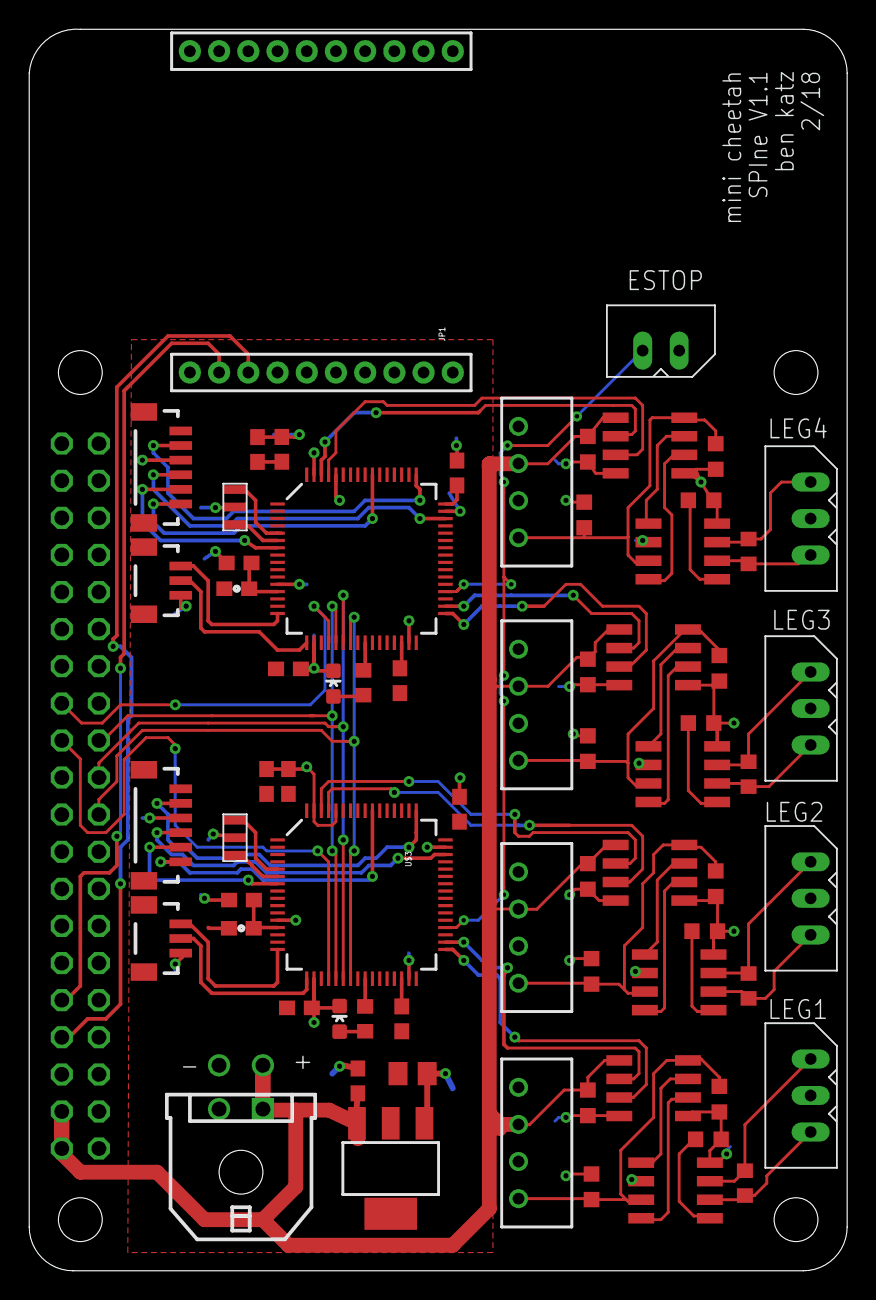
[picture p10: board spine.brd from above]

Board: 2 copper layers, 56.0 x 85.0 mm, 69 parts (0 on the bottom side), 71 nets.

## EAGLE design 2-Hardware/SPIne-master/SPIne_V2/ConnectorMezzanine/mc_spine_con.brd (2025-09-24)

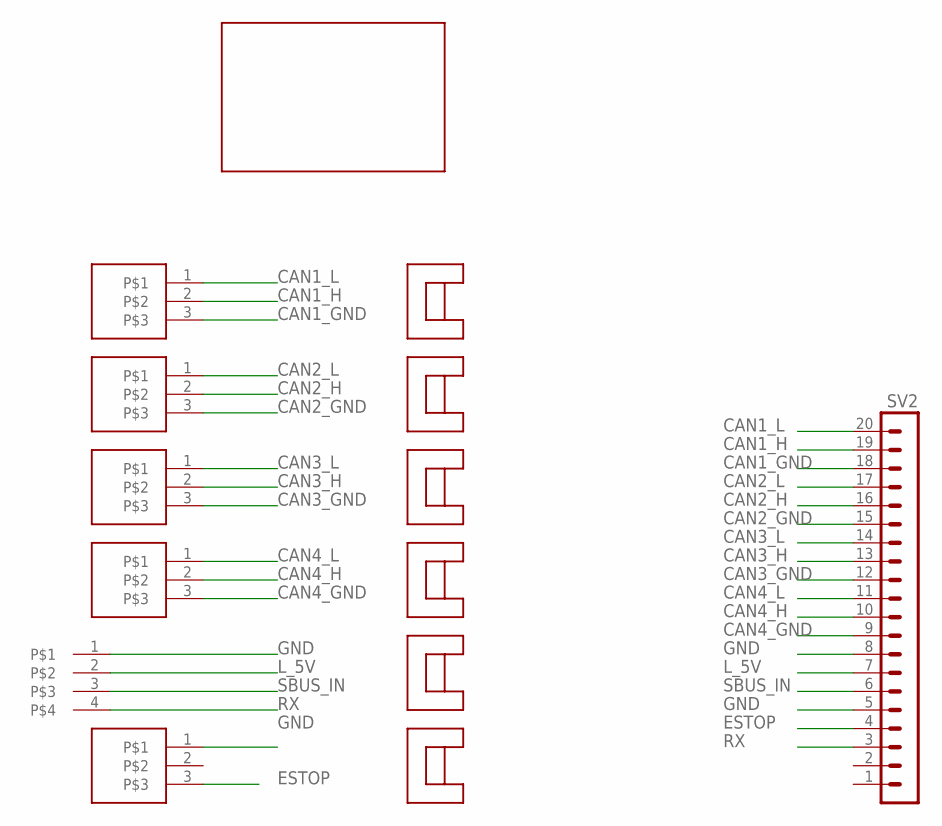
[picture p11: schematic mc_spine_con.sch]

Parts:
SV2: MA20-1L
U$1, U$3, U$4, U$6, U$12: 3-PIN; M80-8430342
U$2: UP_BOARD_NOPINS
U$5: 4-PIN; M80-8430442
U$7, U$8, U$9, U$10, U$11, U$13: SMD_CABLE_CLIPSS8111-46R; S8111-46R

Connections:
CAN1_GND: SV2.18, U$12.3
CAN1_H: SV2.19, U$12.2
CAN1_L: SV2.20, U$12.1
CAN2_GND: SV2.15, U$1.3
CAN2_H: SV2.16, U$1.2
CAN2_L: SV2.17, U$1.1
CAN3_GND: SV2.12, U$3.3
CAN3_H: SV2.13, U$3.2
CAN3_L: SV2.14, U$3.1
CAN4_GND: SV2.9, U$4.3
CAN4_H: SV2.10, U$4.2
CAN4_L: SV2.11, U$4.1
ESTOP: SV2.4, U$6.3
GND: SV2.5, SV2.8, U$5.1, U$6.1
L_5V: SV2.7, U$5.2
RX: SV2.3, U$5.4
SBUS_IN: SV2.6, U$5.3

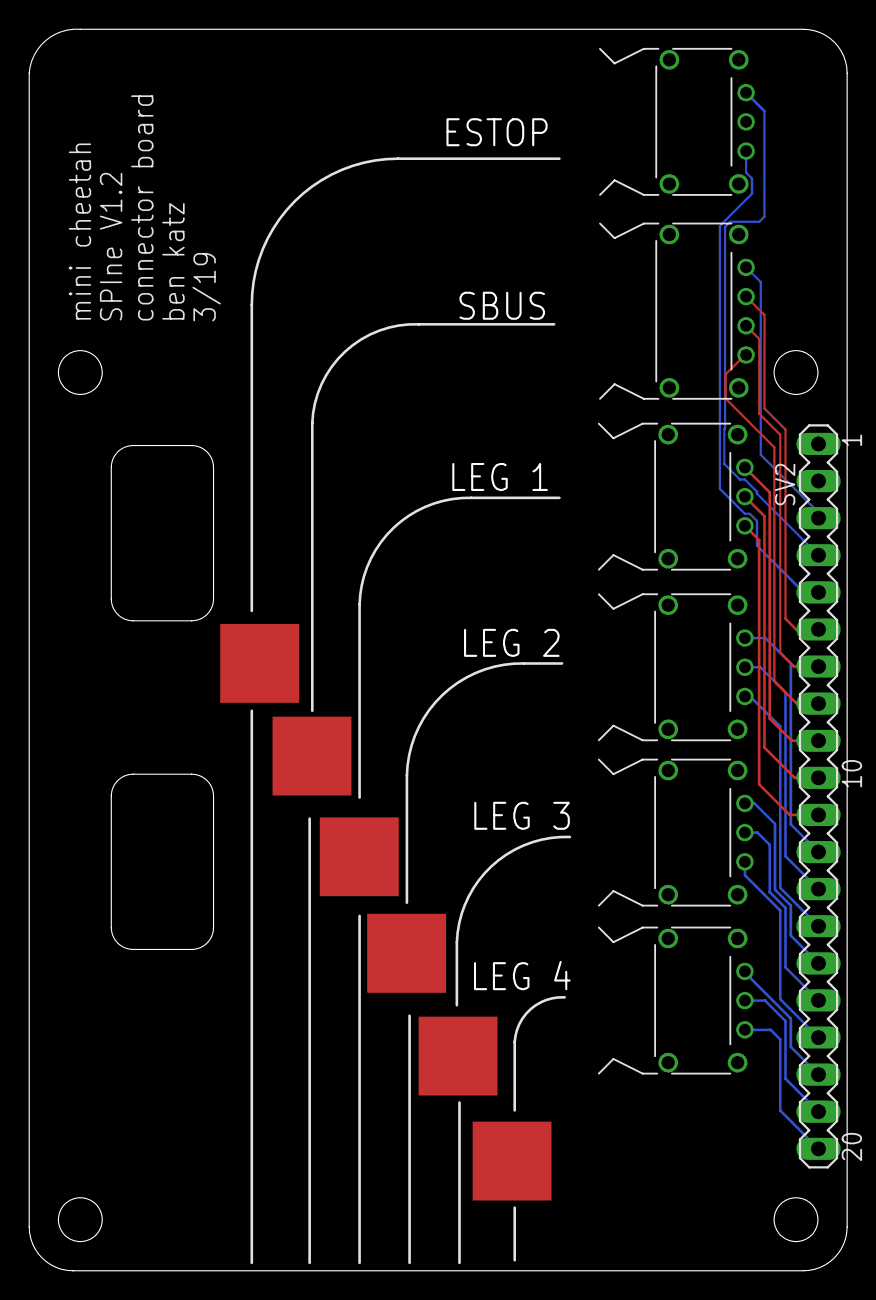
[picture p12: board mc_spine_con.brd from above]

Board: 2 copper layers, 56.0 x 85.0 mm, 14 parts (0 on the bottom side), 17 nets.

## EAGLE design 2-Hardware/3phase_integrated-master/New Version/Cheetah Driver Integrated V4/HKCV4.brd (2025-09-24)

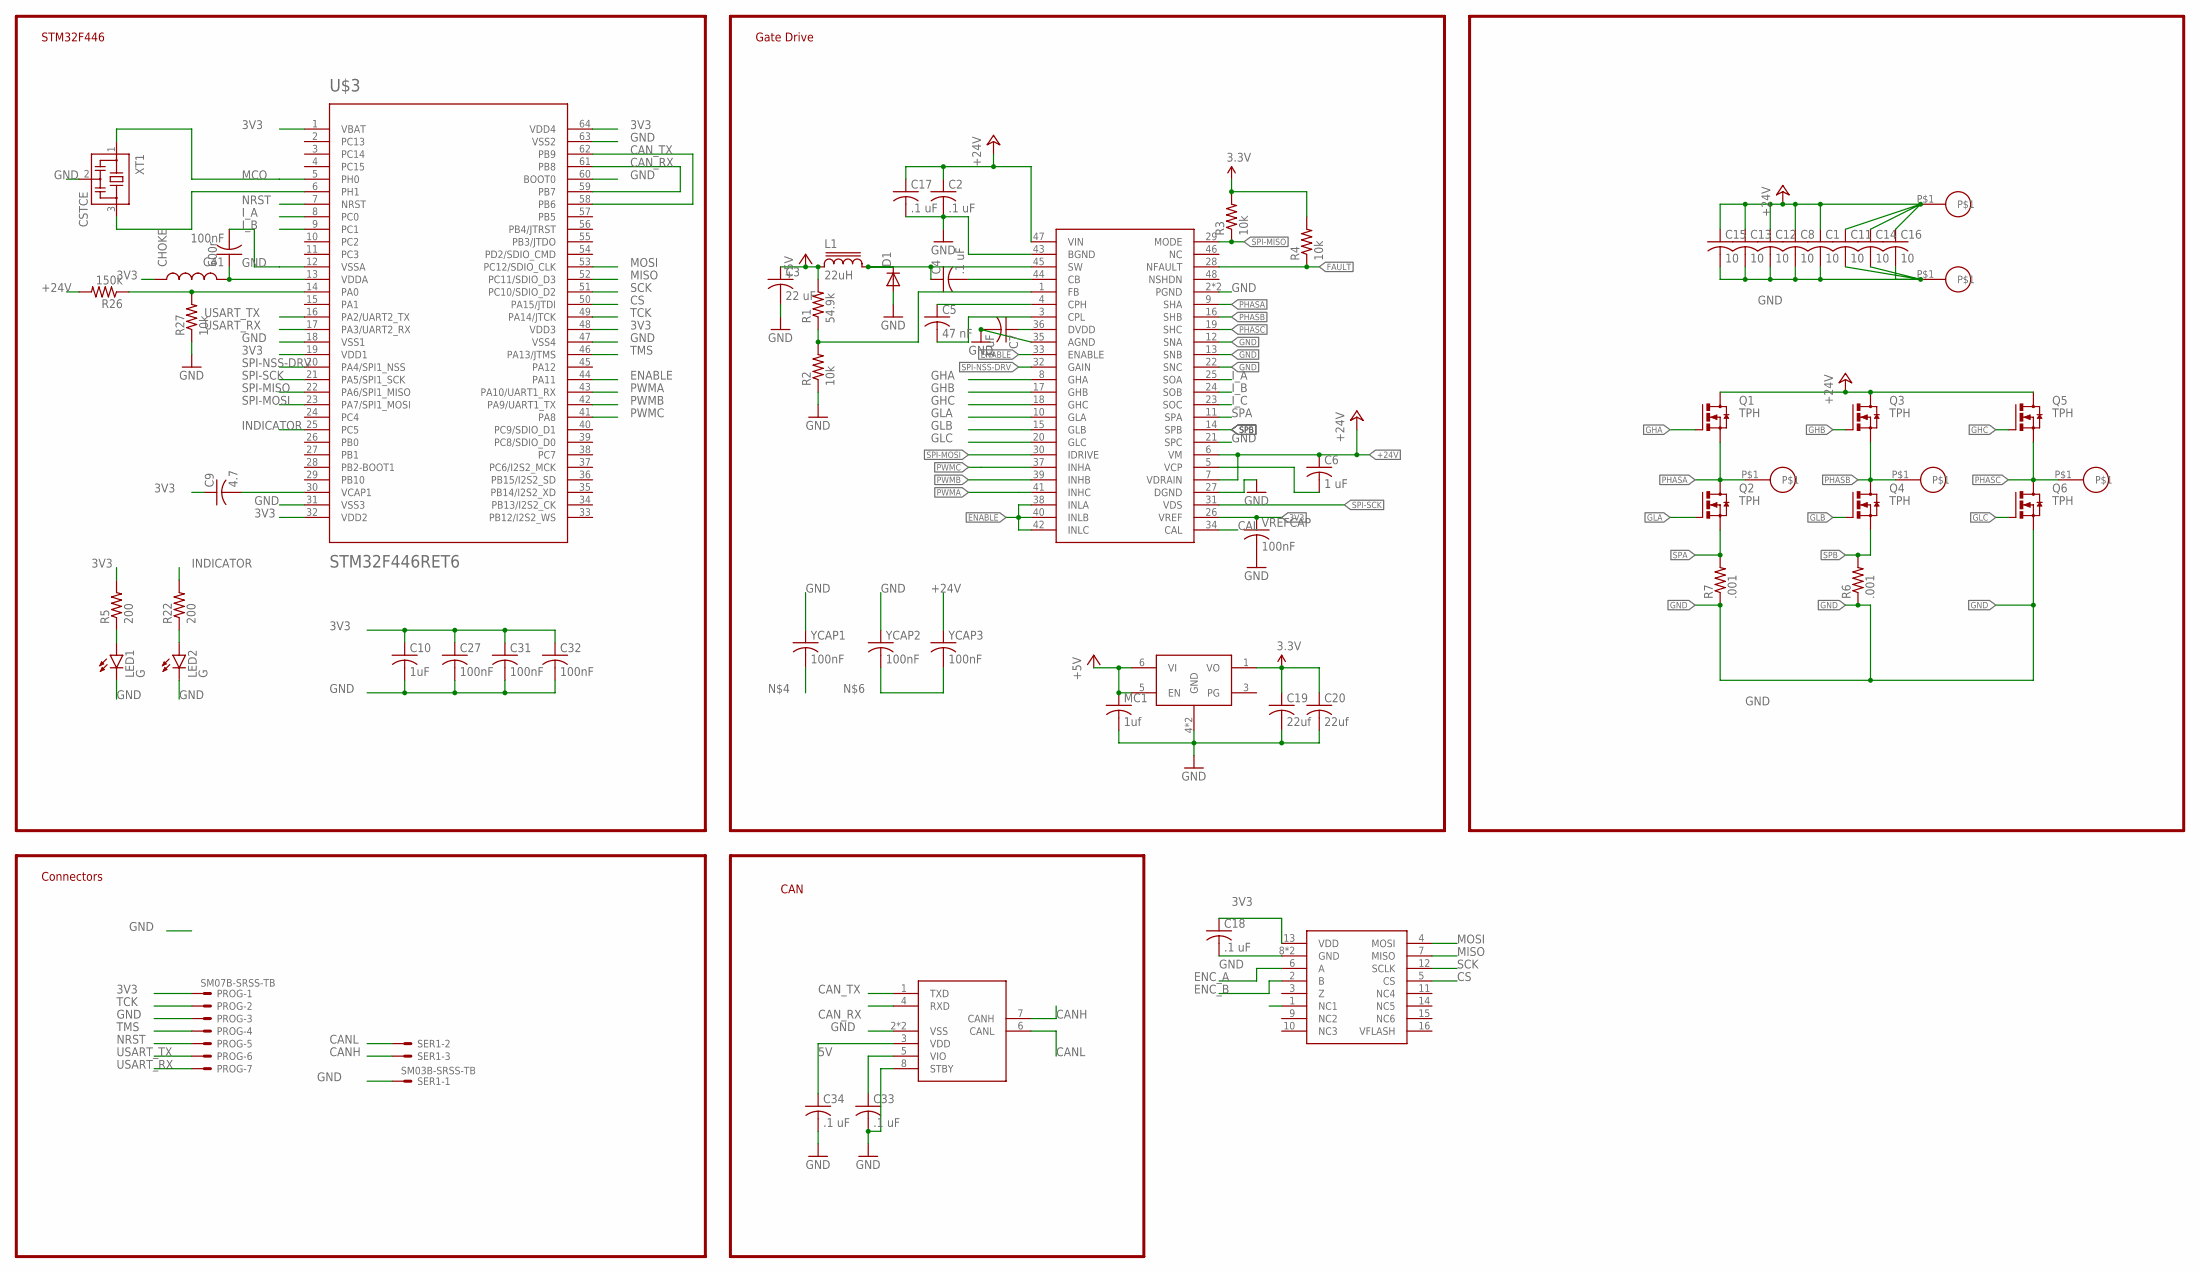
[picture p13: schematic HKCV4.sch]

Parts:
C1, C8, C11, C12, C13, C14, C15, C16: 10; C1206K
C2, C4: .1 uF; C0603K
C3: 22 uF; C0603K
C5: 47 nF; C0402K
C6: 1 uF; C0603K
C7: 1 uF; C0402K
C9: 4.7; C0402K
C10: 1uF; C0402K
C17: .1 uF; C1206K
C18, C33, C34: .1 uF; C0402K
C19, C20: 22uf; C0603K
C27, C31, C32: 100nF; C0402K
C41: 100nF; C0402
CHOKE: 600r; 0603
D1: DIODE-SOD123; SOD123
L1: 22uH; SDR0302
LED1, LED2: G; LED-0603
MC1: 1uf; C0402
PROG: SM07B-SRSS-TB
Q1, Q2, Q3, Q4, Q5, Q6: TPH; TRANS_TPH5900CNH,L1Q
R1: 54.9k; R0402
R2, R3, R4, R27: 10k; R0402
R5, R22: 200; R0402
R6, R7: .001; R1210
R26: 150k; R0402
SER1: SM03B-SRSS-TB
U$1: DRV8323RH; QFN50P700X700X90-49N
U$2, U$4, U$5, U$8, U$10: 18_AWG_PAD
U$3: STM32F446RET6; TQFP64
U$6: MCP2542; TDFN
U$7: LDFM; DFN6-3X3
U$11: MA700; QFN16
VREFCAP: 100nF; C0402K
XT1: CSTCE
YCAP1, YCAP2, YCAP3: 100nF; C0402K

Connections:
3V3: C9.1, C10.1, C18.1, C19.1, C20.1, C27.1, C31.1, C32.1, C33.1, CHOKE.1, PROG.1, R3.2, R4.2, R5.2, U$1.26 (VREF), U$3.1 (VBAT), U$3.19 (VDD1), U$3.32 (VDD2), U$3.48 (VDD3), U$3.64 (VDD4), U$6.5 (VIO), U$7.1 (VO), U$11.13 (VDD), VREFCAP.1
5V: C3.1, C34.1, L1.1, MC1.1, R1.2, U$6.3 (VDD), U$7.5 (EN), U$7.6 (VI)
+24V: C1.1, C2.1, C6.1, C8.1, C11.1, C12.1, C13.1, C14.1, C15.1, C16.1, C17.1, Q1.5 (D), Q1.6 (D), Q1.7 (D), Q1.8 (D), Q1.EP (D), Q3.5 (D), Q3.6 (D), Q3.7 (D), Q3.8 (D), Q3.EP (D), Q5.5 (D), Q5.6 (D), Q5.7 (D), Q5.8 (D), Q5.EP (D), R26.2, U$1.6 (VM), U$1.7 (VDRAIN), U$1.47 (VIN), U$8.P$1, YCAP3.1
BOOT: C4.2, U$1.44 (CB)
CAL: U$1.34 (CAL)
CANH: SER1.3, U$6.7 (CANH)
CANL: SER1.2, U$6.6 (CANL)
CAN_RX: U$3.59 (PB7), U$3.61 (PB8), U$6.4 (RXD)
CAN_TX: U$3.58 (PB6), U$3.62 (PB9), U$6.1 (TXD)
CPH: C5.1, U$1.4 (CPH)
CPL: C5.2, U$1.3 (CPL)
CS: U$3.50 (PA15/JTDI), U$11.5 (CS)
DEVICE3.3: C7.1, U$1.36 (DVDD)
ENABLE: U$1.33 (ENABLE), U$1.38 (INLA), U$1.40 (INLB), U$1.42 (INLC), U$3.44 (PA11)
ENC_A: U$11.6 (A)
ENC_B: U$11.2 (B)
FAULT: R4.1, U$1.28 (NFAULT)
FB: R1.1, R2.2, U$1.1 (FB)
GHA: Q1.4 (G), U$1.8 (GHA)
GHB: Q3.4 (G), U$1.17 (GHB)
GHC: Q5.4 (G), U$1.18 (GHC)
GLA: Q2.4 (G), U$1.10 (GLA)
GLB: Q4.4 (G), U$1.15 (GLB)
GLC: Q6.4 (G), U$1.20 (GLC)
GND: C1.2, C2.2, C3.2, C7.2, C8.2, C10.2, C11.2, C12.2, C13.2, C14.2, C15.2, C16.2, C17.2, C18.2, C19.2, C20.2, C27.2, C31.2, C32.2, C33.2, C34.2, C41.2, D1.A, LED1.C, LED2.C, MC1.2, PROG.3, Q6.1 (S), Q6.2 (S), Q6.3 (S), R2.1, R6.1, R7.1, R27.1, SER1.1, U$1.2 (PGND), U$1.12 (SNA), U$1.13 (SNB), U$1.21 (SPC), U$1.22 (SNC), U$1.27 (DGND), U$1.35 (AGND), U$1.43 (BGND), U$1.49 (PGND), U$3.12 (VSSA), U$3.18 (VSS1), U$3.31 (VSS3), U$3.47 (VSS4), U$3.60 (BOOT0), U$3.63 (VSS2), U$6.2 (VSS), U$6.8 (STBY), U$6.9 (VSS), U$7.4 (GND), U$7.EXP (GND), U$10.P$1, U$11.8 (GND), U$11.TH (GND), VREFCAP.2, XT1.2, YCAP1.1, YCAP2.1
INDICATOR: R22.2, U$3.25 (PC5)
I_A: U$1.25 (SOA), U$3.8 (PC0)
I_B: U$1.24 (SOB), U$3.9 (PC1)
I_C: U$1.23 (SOC)
MCO: U$3.5 (PH0), XT1.1
MISO: U$3.52 (PC11/SDIO_D3), U$11.7 (MISO)
MOSI: U$3.53 (PC12/SDIO_CLK), U$11.4 (MOSI)
unnamed: LED1.A, R5.1
unnamed: C41.1, CHOKE.2, U$3.13 (VDDA)
unnamed: C9.2, U$3.30 (VCAP1)
unnamed: YCAP2.2, YCAP3.2
unnamed: R26.1, R27.2, U$3.14 (PA0)
unnamed: LED2.A, R22.1
unnamed: U$3.6 (PH1), XT1.3
NRST: PROG.5, U$3.7 (NRST)
PHASA: Q1.1 (S), Q1.2 (S), Q1.3 (S), Q2.5 (D), Q2.6 (D), Q2.7 (D), Q2.8 (D), Q2.EP (D), U$1.9 (SHA), U$4.P$1
PHASB: Q3.1 (S), Q3.2 (S), Q3.3 (S), Q4.5 (D), Q4.6 (D), Q4.7 (D), Q4.8 (D), Q4.EP (D), U$1.16 (SHB), U$2.P$1
PHASC: Q5.1 (S), Q5.2 (S), Q5.3 (S), Q6.5 (D), Q6.6 (D), Q6.7 (D), Q6.8 (D), Q6.EP (D), U$1.19 (SHC), U$5.P$1
PWMA: U$1.41 (INHC), U$3.43 (PA10/UART1_RX)
PWMB: U$1.39 (INHB), U$3.42 (PA9/UART1_TX)
PWMC: U$1.37 (INHA), U$3.41 (PA8)
SCK: U$3.51 (PC10/SDIO_D2), U$11.12 (SCLK)
SPA: Q2.1 (S), Q2.2 (S), Q2.3 (S), R7.2, U$1.11 (SPA)
SPB: Q4.1 (S), Q4.2 (S), Q4.3 (S), R6.2, U$1.14 (SPB)
SPI-MISO: R3.1, U$1.29 (MODE), U$3.22 (PA6/SPI1_MISO)
SPI-MOSI: U$1.30 (IDRIVE), U$3.23 (PA7/SPI1_MOSI)
SPI-NSS-DRV: U$1.32 (GAIN), U$3.20 (PA4/SPI1_NSS)
SPI-SCK: U$1.31 (VDS), U$3.21 (PA5/SPI1_SCK)
SW: C4.1, D1.C, L1.2, U$1.45 (SW)
TCK: PROG.2, U$3.49 (PA14/JTCK)
TMS: PROG.4, U$3.46 (PA13/JTMS)
USART_RX: PROG.7, U$3.17 (PA3/UART2_RX)
USART_TX: PROG.6, U$3.16 (PA2/UART2_TX)
VCP: C6.2, U$1.5 (VCP)

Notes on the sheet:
Gate Drive
STM32F446
CAN
Connectors

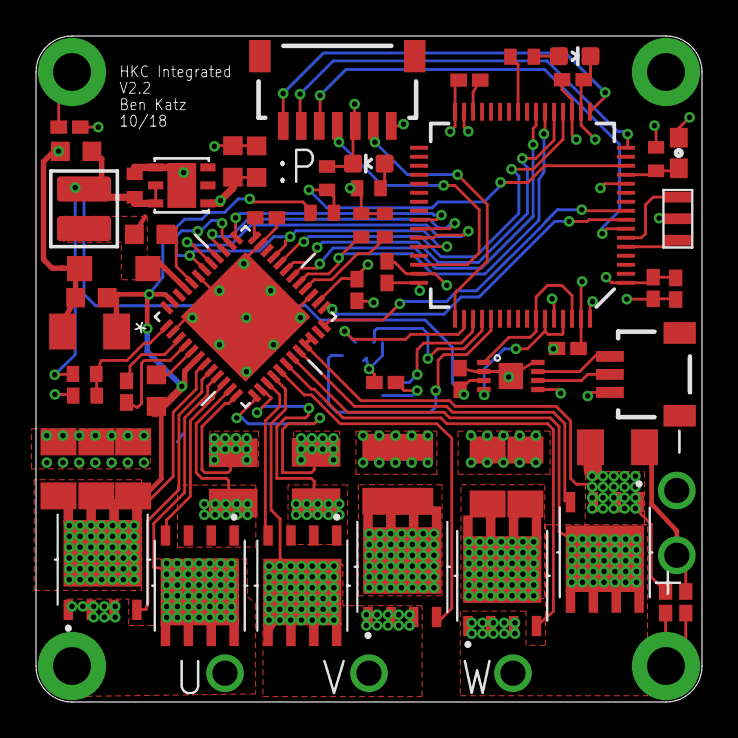
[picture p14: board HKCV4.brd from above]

Board: 4 copper layers, 37.0 x 37.0 mm, 65 parts (1 on the bottom side), 55 nets.

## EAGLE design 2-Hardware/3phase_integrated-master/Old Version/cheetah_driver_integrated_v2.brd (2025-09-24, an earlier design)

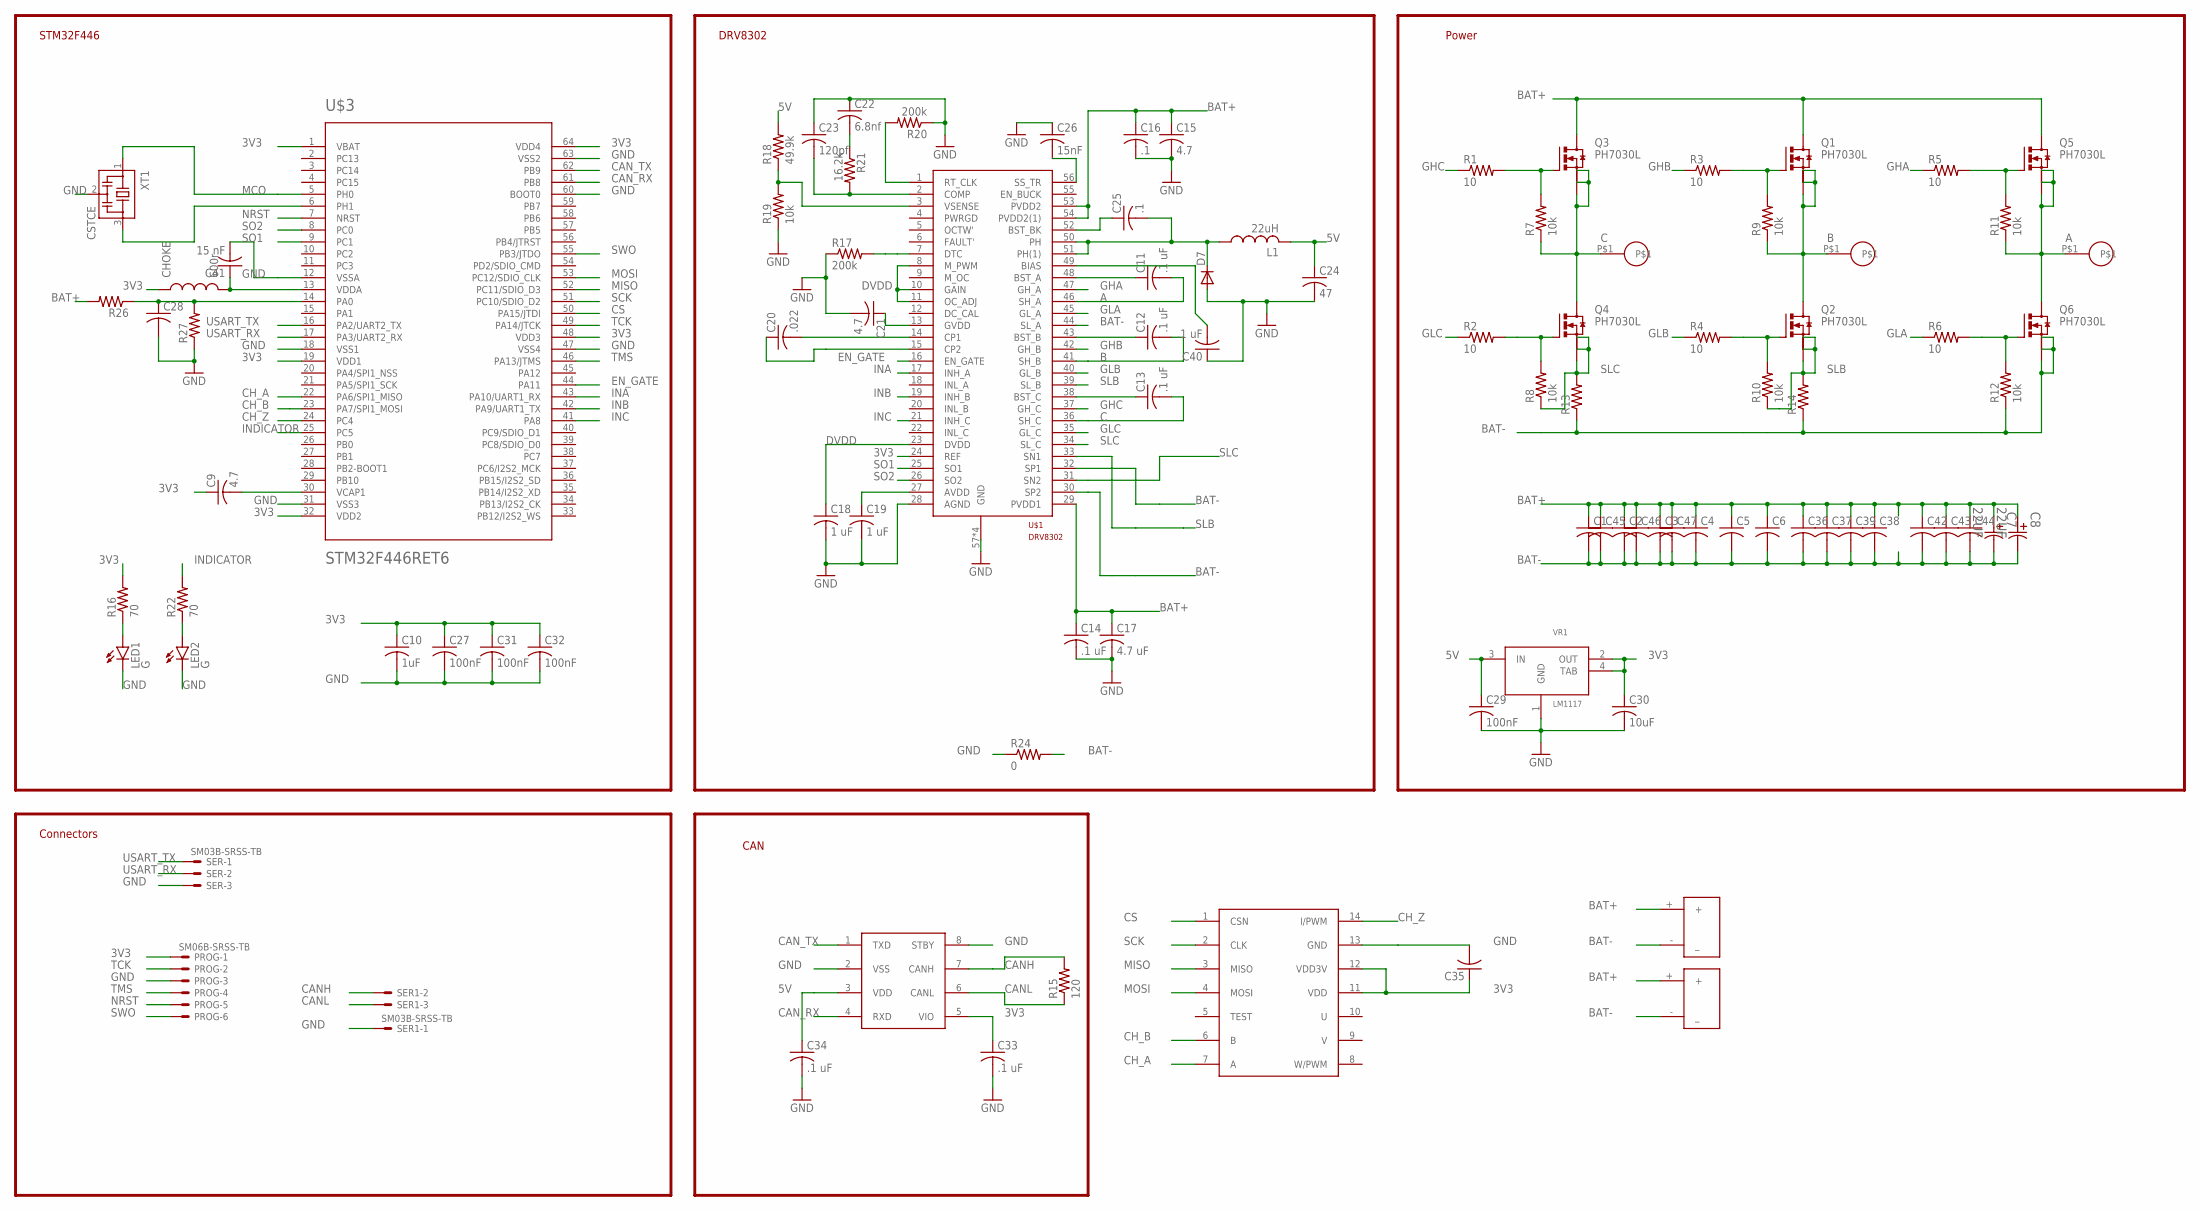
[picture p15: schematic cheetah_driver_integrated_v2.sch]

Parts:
C1, C2, C3, C4, C5, C6, C36, C37, C38, C39, C42, C43, C44, C45, C46, C47: C-USC1206; C1206
C7, C8: 22UF; CAPAE660X610N
C9: 4.7; C0603
C10: 1uF; C0603
C11, C12, C13, C14, C40: .1 uF; C0603
C15, C21: 4.7; C0805
C16, C25: .1; C0603
C17: 4.7 uF; C0805
C18, C19: 1 uF; C0603
C20: .022; C0603
C22: 6.8nf; C0603
C23: 120pf; C0603
C24: 47; C1210
C26: 15nF; C0603
C27, C29, C31, C32: 100nF; C0603
C28, C35: C-USC0603; C0603
C30: 10uF; C0805K
C33, C34: .1 uF; C0603K
C41: 15 nF; C0603
CHOKE: 600r; 0603
D7: DIODE-DO-214AC; DO-214AC
L1: 22uH; L4532P
LED1, LED2: G; LED-0603
PROG: SM06B-SRSS-TB
Q1, Q2, Q3, Q4, Q5, Q6: PH7030L; SOT669
R1, R2, R3, R4, R5, R6: 10; R0603
R7, R8, R9, R10, R11, R12, R19: 10k; R0603
R13, R14: R-US_R1210; R1210
R15: 120; R0603
R16, R22: 70; R0603
R17, R20: 200k; R0603
R18: 49.9k; R0603
R21: 16.2k; R0603
R24: 0; R0603
R26, R27: R-US_R0603; R0603
SER, SER1: SM03B-SRSS-TB
U$1: DRV8302; HTSSOP56
U$2, U$4, U$5: 18_AWG_PAD
U$3: STM32F446RET6; TQFP64
U$6: MCP2561; SO08
U$7: AS5147P; TSSOP14
U$8, U$9: DC_CONNECTOR; XT30_HORIZONTAL
VR1: LM1117; SOT-223
XT1: CSTCE

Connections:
3V3: C9.1, C10.1, C27.1, C30.1, C31.1, C32.1, C33.1, C35.1, CHOKE.1, PROG.1, R16.2, U$1.24 (REF), U$3.1 (VBAT), U$3.19 (VDD1), U$3.32 (VDD2), U$3.48 (VDD3), U$3.64 (VDD4), U$6.5 (VIO), U$7.11 (VDD), U$7.12 (VDD3V), VR1.2 (OUT), VR1.4 (TAB)
5V: C24.1, C29.1, C34.1, L1.2, R18.2, U$6.3 (VDD), VR1.3 (IN)
A: C11.2, Q5.1 (S), Q5.2 (S), Q5.3 (S), Q6.MB (D), R11.1, U$1.46 (SH_A), U$5.P$1
B: C12.2, Q1.1 (S), Q1.2 (S), Q1.3 (S), Q2.MB (D), R9.1, U$1.41 (SH_B), U$4.P$1
BAT+: C1.1, C2.1, C3.1, C4.1, C5.1, C6.1, C7.1, C8.1, C14.1, C15.1, C16.1, C17.1, C36.1, C37.1, C38.1, C39.1, C42.1, C43.1, C44.1, C45.1, C46.1, C47.1, Q1.MB (D), Q3.MB (D), Q5.MB (D), R26.2, U$1.29 (PVDD1), U$1.53 (PVDD2), U$1.54 (PVDD2(1)), U$8.+, U$9.+
BAT-: C1.2, C2.2, C3.2, C4.2, C5.2, C6.2, C7.2, C8.2, C36.2, C37.2, C38.2, C39.2, C42.2, C43.2, C44.2, C45.2, C46.2, C47.2, Q6.1 (S), Q6.2 (S), Q6.3 (S), R12.1, R13.1, R14.1, R24.2, U$1.30 (SP2), U$1.32 (SP1), U$1.44 (SL_A), U$8.- (_), U$9.- (_)
C: C13.2, Q3.1 (S), Q3.2 (S), Q3.3 (S), Q4.MB (D), R7.1, U$1.36 (SH_C), U$2.P$1
CANH: R15.2, SER1.2, U$6.7 (CANH)
CANL: R15.1, SER1.3, U$6.6 (CANL)
CAN_RX: U$3.61 (PB8), U$6.4 (RXD)
CAN_TX: U$3.62 (PB9), U$6.1 (TXD)
CH_A: U$3.22 (PA6/SPI1_MISO), U$7.7 (A)
CH_B: U$3.23 (PA7/SPI1_MOSI), U$7.6 (B)
CH_Z: U$3.24 (PC4), U$7.14 (I/PWM)
CS: U$3.50 (PA15/JTDI), U$7.1 (CSN)
DVDD: C18.1, U$1.8 (M_PWM), U$1.10 (GAIN), U$1.11 (OC_ADJ), U$1.23 (DVDD)
EN_GATE: U$1.16 (EN_GATE), U$3.44 (PA11)
GHA: R5.1, U$1.47 (GH_A)
GHB: R3.1, U$1.42 (GH_B)
GHC: R1.1, U$1.37 (GH_C)
GLA: R6.1, U$1.45 (GL_A)
GLB: R4.1, U$1.40 (GL_B)
GLC: R2.1, U$1.35 (GL_C)
GND: C10.2, C14.2, C15.2, C16.2, C17.2, C18.2, C19.2, C21.2, C22.1, C23.1, C24.2, C26.1, C27.2, C28.2, C29.2, C30.2, C31.2, C32.2, C33.2, C34.2, C35.2, C40.1, C41.2, D7.A, LED1.C, LED2.C, PROG.3, R17.1, R19.1, R20.1, R24.1, R27.1, SER.3, SER1.1, U$1.28 (AGND), U$1.57 (GND), U$1.P$1 (GND), U$1.P$2 (GND), U$1.P$3 (GND), U$3.12 (VSSA), U$3.18 (VSS1), U$3.31 (VSS3), U$3.47 (VSS4), U$3.60 (BOOT0), U$3.63 (VSS2), U$6.2 (VSS), U$6.8 (STBY), U$7.13 (GND), VR1.1 (GND), XT1.2
INA: U$1.17 (INH_A), U$3.43 (PA10/UART1_RX)
INB: U$1.19 (INH_B), U$3.42 (PA9/UART1_TX)
INC: U$1.21 (INH_C), U$3.41 (PA8)
INDICATOR: R22.2, U$3.25 (PC5)
MCO: U$3.5 (PH0), XT1.1
MISO: U$3.52 (PC11/SDIO_D3), U$7.3 (MISO)
MOSI: U$3.53 (PC12/SDIO_CLK), U$7.4 (MOSI)
unnamed: Q3.4 (G), R1.2, R7.2
unnamed: C41.1, CHOKE.2, U$3.13 (VDDA)
unnamed: C9.2, U$3.30 (VCAP1)
unnamed: C11.1, U$1.48 (BST_A)
unnamed: C40.2, U$1.49 (BIAS)
unnamed: C13.1, U$1.38 (BST_C)
unnamed: Q4.4 (G), R2.2, R8.2
unnamed: Q1.4 (G), R3.2, R9.2
unnamed: C12.1, U$1.43 (BST_B)
unnamed: Q5.4 (G), R5.2, R11.2
unnamed: Q6.4 (G), R6.2, R12.2
unnamed: R18.1, R19.2, U$1.3 (VSENSE)
unnamed: R17.2, U$1.7 (DTC)
unnamed: C19.1, U$1.27 (AVDD)
unnamed: C20.2, U$1.14 (CP1)
unnamed: C20.1, U$1.15 (CP2)
unnamed: C21.1, U$1.13 (GVDD)
unnamed: C23.2, R21.2, U$1.2 (COMP)
unnamed: R20.2, U$1.1 (RT_CLK)
unnamed: C22.2, R21.1
unnamed: C25.2, D7.C, L1.1, U$1.50 (PH), U$1.51 (PH(1))
unnamed: C25.1, U$1.52 (BST_BK)
unnamed: C26.2, U$1.56 (SS_TR)
unnamed: C28.1, R26.1, R27.2, U$3.14 (PA0)
unnamed: LED1.A, R16.1
unnamed: Q2.4 (G), R4.2, R10.2
unnamed: LED2.A, R22.1
unnamed: U$3.6 (PH1), XT1.3
NRST: PROG.5, U$3.7 (NRST)
SCK: U$3.51 (PC10/SDIO_D2), U$7.2 (CLK)
SLB: Q2.1 (S), Q2.2 (S), Q2.3 (S), R10.1, R14.2, U$1.33 (SN1), U$1.39 (SL_B)
SLC: Q4.1 (S), Q4.2 (S), Q4.3 (S), R8.1, R13.2, U$1.31 (SN2), U$1.34 (SL_C)
SO1: U$1.25 (SO1), U$3.9 (PC1)
SO2: U$1.26 (SO2), U$3.8 (PC0)
SWO: PROG.6, U$3.55 (PB3/JTDO)
TCK: PROG.2, U$3.49 (PA14/JTCK)
TMS: PROG.4, U$3.46 (PA13/JTMS)
USART_RX: SER.2, U$3.17 (PA3/UART2_RX)
USART_TX: SER.1, U$3.16 (PA2/UART2_TX)

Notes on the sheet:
DRV8302
STM32F446
Connectors
Power
CAN

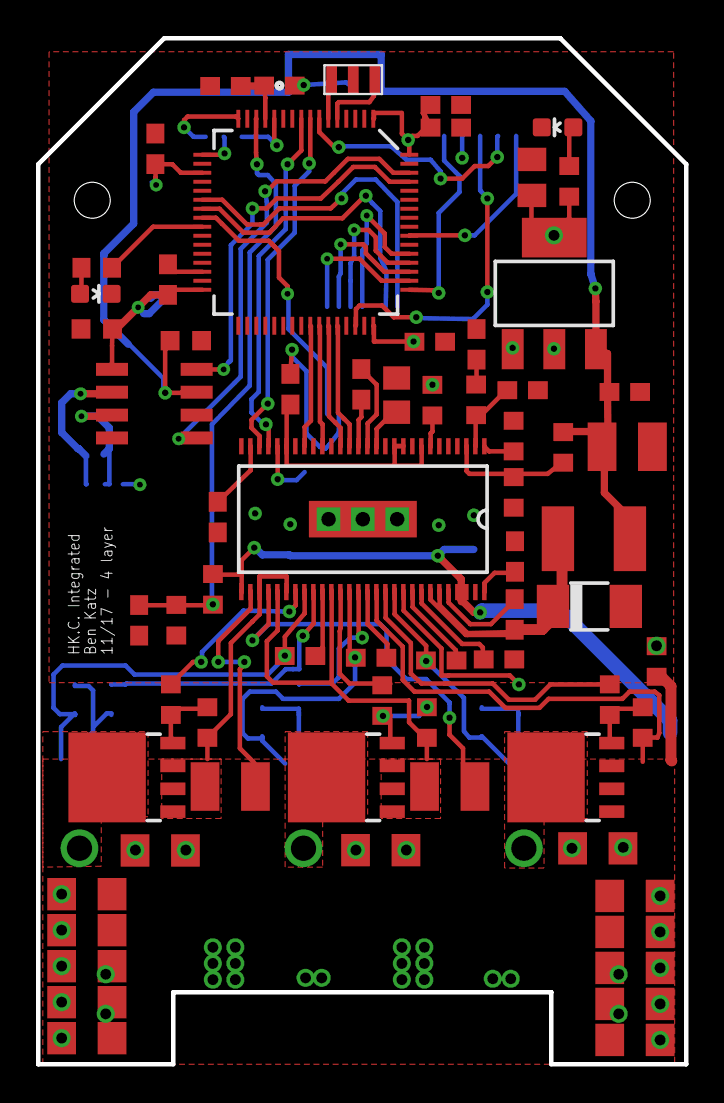
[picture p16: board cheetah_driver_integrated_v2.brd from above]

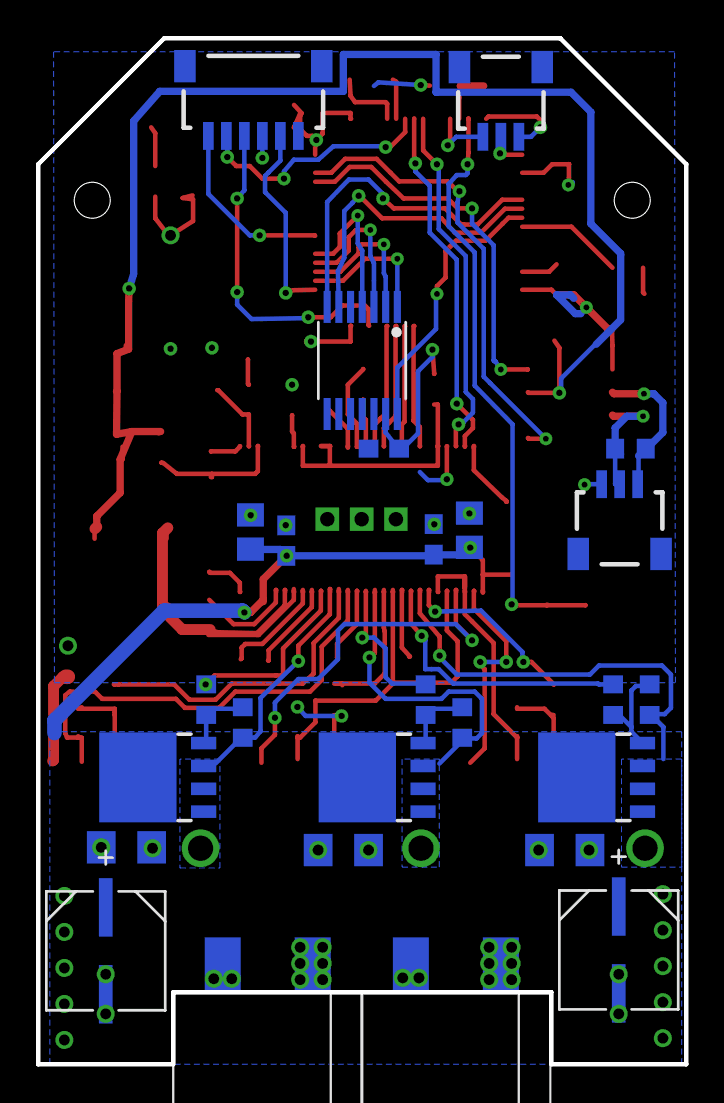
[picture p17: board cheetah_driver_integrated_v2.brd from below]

Board: 4 copper layers, 36.0 x 57.0 mm, 97 parts (26 on the bottom side), 70 nets.

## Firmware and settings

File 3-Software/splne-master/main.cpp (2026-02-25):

// main.cpp — Spine（SPI 从机 + CAN 桥）完整修复版
#include "mbed.h"
#include "math_ops.h"
#include <cstring>
#include "leg_message.h"

// 文件概览：腿控板作为 SPI 从机接收主机命令并通过两路 CAN 驱动电机，同时返回状态。
// Google 风格：简要说明文件职责，便于快速理解模块边界。

// -------------------- 配置 --------------------
#define RX_LEN   66    // SPI 收包 16bit 字数
#define TX_LEN   66    // SPI 发包 16bit 字数

#define DATA_LEN 30    // 30 x 16bit = 60B（12 个 float + flags + 32-bit 校验）
#define CMD_LEN  66    // 66 x 16bit（32 个 u32 + 32-bit 校验）

#define CAN_ID   0x0

/// Value Limits（物理约束） ///
#define P_MIN -12.5f
#define P_MAX  12.5f
#define V_MIN -65.0f
#define V_MAX  65.0f
#define KP_MIN 0.0f
#define KP_MAX 500.0f
#define KD_MIN 0.0f
#define KD_MAX 5.0f
#define T_MIN -23.5f
#define T_MAX  23.5f

/// Joint Soft Stops（软限位） ///
#define A_LIM_P 1.5f
#define A_LIM_N -1.5f
#define H_LIM_P 5.0f
#define H_LIM_N -5.0f
#define K_LIM_P 0.2f
#define K_LIM_N 7.7f
#define KP_SOFTSTOP 100.0f
#define KD_SOFTSTOP 0.4f;

#define STRICT_DROP_ON_CRC_FAIL 1   // CRC 失败是否直接丢弃命令
#define CUT_MOTOR_ON_BAD_SPI    1   // 连续 CRC 失败是否触发断电
#define SPI_BAD_STREAK_MAX      5   // 触发断电的连续失败阈值

// -------------------- 全局对象 --------------------
spi_data_t    spi_data;         // spine -> host：回传的两腿状态与校验
spi_command_t spi_command;      // host  -> spine：经校验后的最新指令
static spi_command_t spi_rx_shadow;    // SPI ISR 暂存的命令，待主循环搬运

static uint16_t rx_buff[RX_LEN];       // SPI 半字接收缓存
static uint16_t tx_buff[TX_LEN];       // SPI 半字发送缓存

DigitalOut led(PC_5);                   // 急停指示灯（亮=急停触发）
Serial     pc(PA_2, PA_3);              // 上位机调试串口

// 与硬件一致的 CAN 引脚
CAN can1(PB_12, PB_13, 1000000);        // CAN1：第一条腿
CAN can2(PB_8,  PB_9,  1000000);        // CAN2：第二条腿

CANMessage rxMsg1, rxMsg2;              // CAN 反馈暂存
CANMessage a1_can, a2_can, h1_can, h2_can, k1_can, k2_can; // 六个关节的命令帧

InterruptIn cs(PA_4);                   // SPI 片选，下降沿触发 ISR
DigitalIn   estop(PB_15);               // 硬件急停输入（上拉，低有效）

leg_state   l1_state, l2_state;         // 两条腿当前状态
leg_control l1_control, l2_control;     // 两条腿待发送的控制量

volatile int enabled = 0;              // 当前是否已进入力矩模式
volatile uint32_t g_spi_frames = 0;    // SPI 已处理的帧数
volatile uint32_t g_cmd_bad    = 0;    // CRC 失败的帧数
volatile int      g_last_len   = 0;    // 上一帧实际接收的半字数
static volatile int spi_ready  = 0;    // SPI 是否完成初始化
static volatile int g_cmd_pending = 0; // 是否有待处理的 SPI 命令帧
static volatile int g_need_cut_motors = 0; // 是否需要立即退出力矩模式
static volatile int g_crc_bad_streak = 0;  // 连续 CRC 失败次数
static volatile int counter2 = 0;      // 站立模式计数器（预留）
static volatile int is_standing = 0;   // 站立模式标志位

// 将 TX 缓冲区的第一个 16bit 预写入 SPI DR，确保片选拉低时立即输出。
static inline void spi_prime_first_word(void){
  if(!spi_ready) return;
  SPI1->DR = tx_buff[0];
}

// 计算 n 个 32-bit 字的逐字 XOR，用于 SPI 命令校验。
static inline uint32_t xor_checksum_u32(const uint32_t* p, size_t n){
  uint32_t s = 0;
  for(size_t i = 0; i < n; i++) {
    s ^= p[i];
  }
  return s;
}

// 根据 TX buffer 前 30 个 16-bit 半字生成 32-bit 序列（低 16bit 在前）并计算 XOR 校验。
static inline uint32_t checksum_from_tx_words30(const uint16_t* w16){
  uint32_t s = 0;
  for (int i = 0; i < 14; i++){
    uint32_t lo = w16[2*i + 0];
    uint32_t hi = w16[2*i + 1];
    s ^= (hi << 16) | lo;  // 与 Jetson 端 calc_lohi 一致
  }
  return s;
}

// ===== CAN 打包/解包 =====
// 将单关节控制量压缩为 8 字节 CAN 帧，遵循电机驱动的打包协议。
void pack_cmd(CANMessage * msg, joint_control joint){
  // 期望值按物理上限限幅，防止驱动接收异常值。
  float p_des = fminf(fmaxf(P_MIN, joint.p_des), P_MAX);
  float v_des = fminf(fmaxf(V_MIN, joint.v_des), V_MAX);
  float kp    = fminf(fmaxf(KP_MIN, joint.kp),  KP_MAX);
  float kd    = fminf(fmaxf(KD_MIN, joint.kd),  KD_MAX);
  float t_ff  = fminf(fmaxf(T_MIN, joint.t_ff), T_MAX);

  uint16_t p_int  = float_to_uint(p_des, P_MIN, P_MAX, 16);
  uint16_t v_int  = float_to_uint(v_des, V_MIN, V_MAX, 12);
  uint16_t kp_int = float_to_uint(kp,    KP_MIN, KP_MAX, 12);
  uint16_t kd_int = float_to_uint(kd,    KD_MIN, KD_MAX, 12);
  uint16_t t_int  = float_to_uint(t_ff,  T_MIN,  T_MAX,  12);

  msg->data[0] = p_int>>8;
  msg->data[1] = p_int&0xFF;
  msg->data[2] = v_int>>4;
  msg->data[3] = ((v_int&0xF)<<4)|(kp_int>>8);
  msg->data[4] = kp_int&0xFF;
  msg->data[5] = kd_int>>4;
  msg->data[6] = ((kd_int&0xF)<<4)|(t_int>>8);
  msg->data[7] = t_int&0xff;
  msg->len     = 8;
}
// 将电机驱动返回的 8 字节状态帧解包到指定腿的状态结构体。
void unpack_reply(CANMessage msg, leg_state * leg){
  uint16_t id    = msg.data[0];
  uint16_t p_int = (msg.data[1]<<8)|msg.data[2];
  uint16_t v_int = (msg.data[3]<<4)|(msg.data[4]>>4);
  uint16_t i_int = ((msg.data[4]&0xF)<<8)|msg.data[5];

  float p = uint_to_float(p_int, P_MIN, P_MAX, 16);
  float v = uint_to_float(v_int, V_MIN, V_MAX, 12);
  float t = uint_to_float(i_int, -T_MAX, T_MAX, 12);

  // 1:髋外展，2:髋，3:膝；写入对应腿状态。
  if(id==1){      leg->a.p = p; leg->a.v = v; leg->a.t = t; }
  else if(id==2){ leg->h.p = p; leg->h.v = v; leg->h.t = t; }
  else if(id==3){ leg->k.p = p; leg->k.v = v; leg->k.t = t; }
}

// 发一轮 6 条 CAN（两腿）
// 将每个关节的期望控制量打包，并设置对应的报文 ID。
void PackAll(){
  pack_cmd(&a1_can, l1_control.a);
  pack_cmd(&a2_can, l2_control.a);
  pack_cmd(&h1_can, l1_control.h);
  pack_cmd(&h2_can, l2_control.h);
  pack_cmd(&k1_can, l1_control.k);
  pack_cmd(&k2_can, l2_control.k);

  a1_can.id = a2_can.id = 0x1;
  h1_can.id = h2_can.id = 0x2;
  k1_can.id = k2_can.id = 0x3;
}
// 依次向两条 CAN 总线写入关节命令，150us 间隔避免突发阻塞。
void WriteAll(){
  can1.write(a1_can); wait_us(150);
  can2.write(a2_can); wait_us(150);
  can1.write(h1_can); wait_us(150);
  can2.write(h2_can); wait_us(150);
  can1.write(k1_can); wait_us(150);
  can2.write(k2_can); wait_us(150);
}

// 电机模式控制
// Zero: 发送 0xFF...0xFE，让驱动清零偏置（立即广播一次）。
void Zero(CANMessage * msg){ for (int i=0;i<7;i++) msg->data[i]=0xFF; msg->data[7]=0xFE; msg->len=8; WriteAll(); }
// EnterMotorMode: 0xFF...0xFC，进入力矩/闭环模式。
void EnterMotorMode(CANMessage * msg){ for (int i=0;i<7;i++) msg->data[i]=0xFF; msg->data[7]=0xFC; msg->len=8; }
// ExitMotorMode: 0xFF...0xFD，退出力矩模式并松刹车。
void ExitMotorMode (CANMessage * msg){ for (int i=0;i<7;i++) msg->data[i]=0xFF; msg->data[7]=0xFD; msg->len=8; }


// 串口中断：处理调试键盘指令，快速切换电机模式或站立状态。
void serial_isr(){
     /// 串口调试指令处理 ///
     while(pc.readable()){
        char c = pc.getc();
        //led = !led;
        // 调试快捷键：Esc 退出力矩，m 进入力矩，s 站立模式，z 零点校准。
        switch(c){
            case(27):
                //loop.detach();
                pc.printf("\n\r exiting motor mode \n\r");
                ExitMotorMode(&a1_can);
                ExitMotorMode(&a2_can);
                ExitMotorMode(&h1_can);
                ExitMotorMode(&h2_can);
                ExitMotorMode(&k1_can);
                ExitMotorMode(&k2_can);
                enabled = 0;
                break;
            case('m'):
                pc.printf("\n\r entering motor mode \n\r");
                EnterMotorMode(&a1_can);
                EnterMotorMode(&a2_can);
                EnterMotorMode(&h1_can);
                EnterMotorMode(&h2_can);
                EnterMotorMode(&k1_can);
                EnterMotorMode(&k2_can);
                wait(.5);
                enabled = 1;
                //loop.attach(&sendCMD, .001);
                break;
            case('s'):
                pc.printf("\n\r standing \n\r");
                counter2 = 0;
                is_standing = 1;
                //stand();
                break;
            case('z'):
                pc.printf("\n\r zeroing \n\r");
                Zero(&a1_can);
                Zero(&a2_can);
                Zero(&h1_can);
                Zero(&h2_can);
                Zero(&k1_can);
                Zero(&k2_can);
                break;
            }
        }
        WriteAll();
        
    }

// 软限位：超出阈值时清零速度与比例增益，并用固定 KD+力矩将关节推回安全区。返回 1 表示已触发。
int softstop_joint(joint_state s, joint_control * c, float limit_p, float limit_n){
  if(s.p >= limit_p){
    c->v_des = 0; c->kp = 0; c->kd = KD_SOFTSTOP; c->t_ff += KP_SOFTSTOP*(limit_p - s.p); return 1;
  } else if(s.p <= limit_n){
    c->v_des = 0; c->kp = 0; c->kd = KD_SOFTSTOP; c->t_ff += KP_SOFTSTOP*(limit_n - s.p); return 1;
  }
  return 0;
}

// 控制主逻辑：根据最新的 spi_command 生成 l1/l2 控制，把反馈写入 spi_data，并构造 tx_buff。
// 步骤：1) 根据 flags 切换力矩模式；2) 将 CAN 反馈写入 spi_data；
//      3) 急停时清零并打出标志；4) 正常时填充主机期望并做软限位；5) 打包 + 校验到 tx_buff。
void control_and_build_tx(){
  // 入/退力矩模式
  const uint32_t torque_en = (spi_command.flags[0] | spi_command.flags[1]) & 0x1;
  if((torque_en == 1) && (enabled==0)){
    enabled = 1;
    EnterMotorMode(&a1_can); can1.write(a1_can);
    EnterMotorMode(&a2_can); can2.write(a2_can);
    EnterMotorMode(&k1_can); can1.write(k1_can);
    EnterMotorMode(&k2_can); can2.write(k2_can);
    EnterMotorMode(&h1_can); can1.write(h1_can);
    EnterMotorMode(&h2_can); can2.write(h2_can);
    pc.printf("[MOTOR] enter torque mode (estop=%d)\n\r", estop.read());
  } else if((torque_en == 0) && (enabled==1)){
    enabled = 0;
    ExitMotorMode(&a1_can); can1.write(a1_can);
    ExitMotorMode(&a2_can); can2.write(a2_can);
    ExitMotorMode(&h1_can); can1.write(h1_can);
    ExitMotorMode(&h2_can); can2.write(h2_can);
    ExitMotorMode(&k1_can); can1.write(k1_can);
    ExitMotorMode(&k2_can); can2.write(k2_can);
    pc.printf("[MOTOR] exit torque mode\n\r");
  }

  // CAN -> spi_data（host 会做坐标还原）
  spi_data.q_abad[0] = l1_state.a.p;  spi_data.q_abad[1] = l2_state.a.p;
  spi_data.q_hip [0] = l1_state.h.p;  spi_data.q_hip [1] = l2_state.h.p;
  spi_data.q_knee[0] = l1_state.k.p;  spi_data.q_knee[1] = l2_state.k.p;
  spi_data.qd_abad[0]= l1_state.a.v;  spi_data.qd_abad[1]= l2_state.a.v;
  spi_data.qd_hip [0]= l1_state.h.v;  spi_data.qd_hip [1]= l2_state.h.v;
  spi_data.qd_knee[0]= l1_state.k.v;  spi_data.qd_knee[1]= l2_state.k.v;

  // 急停按下：清零控制输出，写入特殊标志并点亮 LED。
  if(estop==0){
    memset(&l1_control, 0, sizeof(l1_control));
    memset(&l2_control, 0, sizeof(l2_control));
    spi_data.flags[0] = 0xDEAD;  // 用特殊码提醒上位机：急停触发
    spi_data.flags[1] = 0xDEAD;
    led = 1;
  } else {
    // 正常工作：刷新期望、应用软限位，关闭 LED。
    led = 0;
    memset(&l1_control, 0, sizeof(l1_control));
    memset(&l2_control, 0, sizeof(l2_control));

    // 主机发送的期望值（按既定 SPI 协议顺序）。
    l1_control.a.p_des = spi_command.q_des_abad[0];
    l1_control.a.v_des = spi_command.qd_des_abad[0];
    l1_control.a.kp    = spi_command.kp_abad[0];
    l1_control.a.kd    = spi_command.kd_abad[0];
    l1_control.a.t_ff  = spi_command.tau_abad_ff[0];

    l1_control.h.p_des = spi_command.q_des_hip[0];
    l1_control.h.v_des = spi_command.qd_des_hip[0];
    l1_control.h.kp    = spi_command.kp_hip[0];
    l1_control.h.kd    = spi_command.kd_hip[0];
    l1_control.h.t_ff  = spi_command.tau_hip_ff[0];

    l1_control.k.p_des = spi_command.q_des_knee[0];
    l1_control.k.v_des = spi_command.qd_des_knee[0];
    l1_control.k.kp    = spi_command.kp_knee[0];
    l1_control.k.kd    = spi_command.kd_knee[0];
    l1_control.k.t_ff  = spi_command.tau_knee_ff[0];

    l2_control.a.p_des = spi_command.q_des_abad[1];
    l2_control.a.v_des = spi_command.qd_des_abad[1];
    l2_control.a.kp    = spi_command.kp_abad[1];
    l2_control.a.kd    = spi_command.kd_abad[1];
    l2_control.a.t_ff  = spi_command.tau_abad_ff[1];

    l2_control.h.p_des = spi_command.q_des_hip[1];
    l2_control.h.v_des = spi_command.qd_des_hip[1];
    l2_control.h.kp    = spi_command.kp_hip[1];
    l2_control.h.kd    = spi_command.kd_hip[1];
    l2_control.h.t_ff  = spi_command.tau_hip_ff[1];

    l2_control.k.p_des = spi_command.q_des_knee[1];
    l2_control.k.v_des = spi_command.qd_des_knee[1];
    l2_control.k.kp    = spi_command.kp_knee[1];
    l2_control.k.kd    = spi_command.kd_knee[1];
    l2_control.k.t_ff  = spi_command.tau_knee_ff[1];

    // 软限位 -> flags
    spi_data.flags[0]  = 0;
    spi_data.flags[0] |= softstop_joint(l1_state.a, &l1_control.a, A_LIM_P, A_LIM_N);
    spi_data.flags[0] |= (softstop_joint(l1_state.h, &l1_control.h, H_LIM_P, H_LIM_N))<<1;
    //spi_data.flags[0] |= (softstop_joint(l1_state.k, &l1_control.k, K_LIM_P, K_LIM_N))<<2;

    spi_data.flags[1]  = 0;
    spi_data.flags[1] |= softstop_joint(l2_state.a, &l2_control.a, A_LIM_P, A_LIM_N);
    spi_data.flags[1] |= (softstop_joint(l2_state.h, &l2_control.h, H_LIM_P, H_LIM_N))<<1;
    //spi_data.flags[1] |= (softstop_joint(l2_state.k, &l2_control.k, K_LIM_P, K_LIM_N))<<2;
  }

  // ===== 关键修复：按“线上半字流”计算校验，并回填到 tx_buff[28..29] =====
  // 先把有效负载(28 半字 = 14×u32)写入 tx_buff[0..27]
  for (int i = 0; i < 28; i++) {
    tx_buff[i] = ((uint16_t*)(&spi_data))[i];
  }
  // 基于“将要上线”的 28 半字计算 32-bit XOR
  uint32_t chk = checksum_from_tx_words30(tx_buff);
  tx_buff[28]  = (uint16_t)(chk & 0xFFFF);      // 低 16
  tx_buff[29]  = (uint16_t)(chk >> 16);         // 高 16
  spi_data.checksum = chk;                      // 仅作串口观测（线上以 tx_buff 为准）
  for (int i = 30; i < TX_LEN; i++) tx_buff[i] = 0;  // 清理尾部

  // 将首个 16bit 预写入 SPI1->DR，确保主机采到当前帧。
  spi_prime_first_word();

}

// ===== SPI 中断（全双工搬运）=====
// 片选为低期间：TXE 时塞下一个半字，RXNE 时收主机半字；结束后校验长度与 XOR。
// 校验通过则将 spi_rx_shadow 搬到命令缓冲并置 g_cmd_pending，交由主循环消费。
void spi_isr(void)
{
  int rx_i = 0;
  int tx_i = 1;  // tx_buff[0] 已由 spi_prime_first_word 预写入

  while (cs == 0) {
    uint32_t sr = SPI1->SR;

    if ((sr & SPI_SR_TXE) && (tx_i < TX_LEN)) {
      SPI1->DR = tx_buff[tx_i++];
    }
    if (sr & SPI_SR_RXNE) {
      if (rx_i < RX_LEN) {
        rx_buff[rx_i++] = SPI1->DR;
      } else {
        volatile uint16_t dump = SPI1->DR;
        (void)dump;
      }
    }
  }
  g_last_len = rx_i;

  // 处理溢出：读 DR + SR 清除 OVR 标志，避免下一帧异常。
  if (SPI1->SR & SPI_SR_OVR) {
    volatile uint16_t dump = SPI1->DR;
    (void)dump;
    dump = SPI1->SR;
    (void)dump;
  }
  // 校验 host 命令（按线上 32×u32 = 64 半字 + checksum 的前 32×u32 计算）
  const bool len_ok = (g_last_len == CMD_LEN);
  uint32_t calc_checksum = 0;
  if(len_ok){
    for(int i = 0; i < CMD_LEN; i++){
      ((uint16_t*)(&spi_rx_shadow))[i] = rx_buff[i];
    }
    calc_checksum = xor_checksum_u32((uint32_t*)rx_buff, 32);
  }

  // 严格 CRC：长度或校验失败则丢帧，必要时累计错误触发断电。
  if (!len_ok || (spi_rx_shadow.checksum != calc_checksum)) {
#if STRICT_DROP_ON_CRC_FAIL
    g_cmd_bad++;
#if CUT_MOTOR_ON_BAD_SPI
    if(++g_crc_bad_streak >= SPI_BAD_STREAK_MAX){
      g_need_cut_motors = 1;
    }
#endif
    // 不更新 spi_command/tx_buff，只返回，继续发送上一帧缓存。
    g_spi_frames++;
    spi_prime_first_word();
    return;
#else
    // 宽松模式：即便 CRC 失败也放行（仅调试用）。
#endif
  }

  g_crc_bad_streak = 0;

  // CRC pass: notify main loop to process command
  g_cmd_pending = 1;

  g_spi_frames++;
}

// ===== SPI 初始化 =====
// 配置 16bit Mode0 从机，绑定 CS 下降沿触发 ISR，并预写首个半字。
void init_spi(void){
  pc.printf("SPI Init ...\n\r");
  SPISlave *spi = new SPISlave(PA_7, PA_6, PA_5, PA_4); // MOSI, MISO, SCK, CS
  spi->format(16, 0);       // 16bit, Mode 0
  spi->frequency(5000000);  // 与 Jetson 保持 1MHz
  spi->reply(0xff);
  cs.fall(&spi_isr);
  spi_ready = 1;
  spi_prime_first_word();
  pc.printf("SPI Init done\n\r");
}

// ===== 主入口 =====
// 初始化串口/CAN/SPI，先构造一帧空数据，随后主循环依次：
// 1) 轮询 CAN 反馈；2) 处理 SPI 新命令（如有）；3) 定期输出统计。
int main() {
  wait(1);  // 上电等待，确保驱动和主机稳定
  pc.baud(921600);
  pc.attach(&serial_isr, Serial::RxIrq); // 绑定串口接收中断，处理键盘指令（含 z -> zeroing）
  estop.mode(PullUp);

  // 允许所有标准帧，便于驱动通信与调试。
  can1.filter(0, 0, CANStandard, 0);
  can2.filter(0, 0, CANStandard, 0);

  memset(&tx_buff,   0, sizeof(tx_buff));
  memset(&spi_data,  0, sizeof(spi_data));
  memset(&spi_command, 0, sizeof(spi_command));
  memset(&spi_rx_shadow,0, sizeof(spi_rx_shadow));

  a1_can.len = a2_can.len = h1_can.len = h2_can.len = k1_can.len = k2_can.len = 8; // 关节命令帧 8 字节
  rxMsg1.len = rxMsg2.len = 6;  // 驱动反馈帧 6 字节

  a1_can.id = a2_can.id = 0x1;
  h1_can.id = h2_can.id = 0x2;
  k1_can.id = k2_can.id = 0x3;

  // 先构建一个初始 tx 帧，避免首帧全 0
  control_and_build_tx();

  // SPI 初始化（等待 CS 释放避免低电平期间初始化）
  while(cs.read() == 0){ wait_us(10); }
  init_spi();

  // 500ms 周期打印轻量状态
  Timer t; t.start();
  uint32_t last_ms = 0, last_frames = 0, last_bad = 0;

  while(1) {
    // 1) 轮询 CAN 反馈。
    if (can2.read(rxMsg2)) unpack_reply(rxMsg2, &l2_state);
    if (can1.read(rxMsg1)) unpack_reply(rxMsg1, &l1_state);
    wait_us(50);

    // 2) CRC 连续异常时的保护：必要时立即退出力矩。
    if (g_need_cut_motors) {
      g_need_cut_motors = 0;
#if CUT_MOTOR_ON_BAD_SPI
      if (enabled) {
        ExitMotorMode(&a1_can); can1.write(a1_can);
        ExitMotorMode(&a2_can); can2.write(a2_can);
        ExitMotorMode(&h1_can); can1.write(h1_can);
        ExitMotorMode(&h2_can); can2.write(h2_can);
        ExitMotorMode(&k1_can); can1.write(k1_can);
        ExitMotorMode(&k2_can); can2.write(k2_can);
        enabled = 0;
      }
#endif
    }

    // 3) 有新的 SPI 命令帧：原子搬运 shadow -> command，再刷新 TX/CAN。
    if (g_cmd_pending) {
      __disable_irq();
      spi_command = spi_rx_shadow;
      g_cmd_pending = 0;
      __enable_irq();

      control_and_build_tx();
      PackAll();
      WriteAll();
    }

    // 4) 定期打印 SPI 帧统计，便于调试链路质量。
    uint32_t now = t.read_ms();
    if (now - last_ms >= 500) {
      uint32_t df = g_spi_frames - last_frames;
      uint32_t db = g_cmd_bad    - last_bad;
      last_frames = g_spi_frames;
      last_bad    = g_cmd_bad;
      last_ms     = now;

      pc.printf("[SPI] frames(+%lu), bad(+%lu), total=%lu/%lu, last_len=%d, estop=%d, enabled=%d\n\r",
                (unsigned long)df, (unsigned long)db,
                (unsigned long)g_spi_frames, (unsigned long)g_cmd_bad,
                g_last_len, estop.read(), enabled);
    }
  }
}

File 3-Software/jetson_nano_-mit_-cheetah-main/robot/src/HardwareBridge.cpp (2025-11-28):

/*!
 * @file HardwareBridge.cpp
 * @brief Interface between robot code and robot hardware
 *
 * This class initializes the hardware of both robots and allows the robot
 * controller to access it
 */
#ifdef linux 

#include <sys/mman.h>
#include <unistd.h>
#include <cstring>
#include <thread>
#include <cstdlib>
#include "Configuration.h"

#include "HardwareBridge.h"
//#include "rt/rt_rc_interface.h"
#include "rt/rt_sbus.h"
#include "rt/rt_spi.h"
#include "rt/rt_vectornav.h"
#include "rt/rt_ethercat.h"
#include "main_helper.h"
#include "Utilities/Utilities_print.h"
#include "Utilities/Log.h"

/*!
 * If an error occurs during initialization, before motors are enabled, print
 * error and exit.
 * @param reason Error message string
 * @param printErrno If true, also print C errno
 */
void HardwareBridge::initError(const char* reason, bool printErrno) {
  LOG_CRITICAL("FAILED TO INITIALIZE HARDWARE: {}", reason);

  if (printErrno) {
    LOG_CRITICAL("Error: {}", strerror(errno));
  }

  exit(-1);
}

/*!
 * All hardware initialization steps that are common between Cheetah 3 and Mini Cheetah
 */
void HardwareBridge::initCommon() {
  LOG_INFO("[HardwareBridge] Init stack");
  prefaultStack();
  LOG_INFO("[HardwareBridge] Init scheduler");
  setupScheduler();
  if (!_interfaceLCM.good()) {
    initError("_interfaceLCM failed to initialize\n", false);
  }

  LOG_INFO("[HardwareBridge] Subscribe LCM");
  _interfaceLCM.subscribe("interface", &HardwareBridge::handleGamepadLCM, this);
  _interfaceLCM.subscribe("interface_request",
                          &HardwareBridge::handleControlParameter, this);

  LOG_INFO("[HardwareBridge] Start interface LCM handler");
  _interfaceLcmThread = std::thread(&HardwareBridge::handleInterfaceLCM, this);
}

/*!
 * Run interface LCM
 */
void HardwareBridge::handleInterfaceLCM() {
  while (!_interfaceLcmQuit) _interfaceLCM.handle();
}

/*!
 * Writes to a 16 KB buffer on the stack. If we are using 4K pages for our
 * stack, this will make sure that we won't have a page fault when the stack
 * grows.  Also mlock's all pages associated with the current process, which
 * prevents the cheetah software from being swapped out.  If we do run out of
 * memory, the robot program will be killed by the OOM process killer (and
 * leaves a log) instead of just becoming unresponsive.
 */
void HardwareBridge::prefaultStack() {
  LOG_INFO("[Init] Prefault stack...");
  volatile char stack[MAX_STACK_SIZE];
  memset(const_cast<char*>(stack), 0, MAX_STACK_SIZE);
  if (mlockall(MCL_CURRENT | MCL_FUTURE) == -1) {
    initError(
        "mlockall failed.  This is likely because you didn't run robot as "
        "root.\n",
        true);
  }
}

/*!
 * Configures the scheduler for real time priority
 */
void HardwareBridge::setupScheduler() {
  LOG_INFO("[Init] Setup RT Scheduler...");
  struct sched_param params;
  params.sched_priority = TASK_PRIORITY;
  if (sched_setscheduler(0, SCHED_FIFO, &params) == -1) {
    initError("sched_setscheduler failed.\n", true);
  }
}

/*!
 * LCM Handler for gamepad message
 */
void HardwareBridge::handleGamepadLCM(const lcm::ReceiveBuffer* rbuf,
                                      const std::string& chan,
                                      const gamepad_lcmt* msg) {
  (void)rbuf;
  (void)chan;
  _gamepadCommand.set(msg);
}

/*!
 * LCM Handler for control parameters
 */
void HardwareBridge::handleControlParameter(
    const lcm::ReceiveBuffer* rbuf, const std::string& chan,
    const control_parameter_request_lcmt* msg) {
  (void)rbuf;
  (void)chan;
  if (msg->requestNumber <= _parameter_response_lcmt.requestNumber) {
    // nothing to do!
    LOG_WARN(
        "[HardwareBridge] Warning: the interface has run a ControlParameter "
        "iteration, but there is no new request!");
    // return;
  }

  // sanity check
  s64 nRequests = msg->requestNumber - _parameter_response_lcmt.requestNumber;
  if (nRequests != 1) {
    LOG_ERROR("[ERROR] Hardware bridge: we've missed {} requests",
           nRequests - 1);
  }

  switch (msg->requestKind) {
    case (s8)ControlParameterRequestKind::SET_USER_PARAM_BY_NAME: {
      if(!_userControlParameters) {
        LOG_WARN("[Warning] Got user param {}, but not using user parameters!",
               (char*)msg->name);
      } else {
        std::string name((char*)msg->name);
        ControlParameter& param = _userControlParameters->collection.lookup(name);

        // type check
        if ((s8)param._kind != msg->parameterKind) {
          throw std::runtime_error(
              "type mismatch for parameter " + name + ", robot thinks it is " +
              controlParameterValueKindToString(param._kind) +
              " but received a command to set it to " +
              controlParameterValueKindToString(
                  (ControlParameterValueKind)msg->parameterKind));
        }
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

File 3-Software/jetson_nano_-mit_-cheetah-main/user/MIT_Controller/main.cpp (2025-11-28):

/*!
 * @file main.cpp
 * @brief Main Function for the WBC Controller
 *
 * The main function parses command line arguments and starts the appropriate
 * driver.
 */

#include <main_helper.h>
#include "MIT_Controller.hpp"
#include "Utilities/Log.h"

int main(int argc, char** argv) {
  initLogger();
  main_helper(argc, argv, new MIT_Controller());
  return 0;
}

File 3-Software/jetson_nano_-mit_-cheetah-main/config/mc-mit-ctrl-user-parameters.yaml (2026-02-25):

# Generated on Mon Aug  5 18:20:08 2019
__collection-name__: user-parameters

Kd_joint          : [1.0, 0.5, 0.5] # Balanced damping
Kp_joint          : [6, 6, 6]     # Medium stiffness for better disturbance rejection

#Kp_body           : [100, 100, 100]
#Kd_body           : [10, 10, 10]

#Kp_foot           : [500, 500, 500]
#Kd_foot           : [20, 20, 20]

#Kp_ori            : [100, 100, 100]
#Kd_ori            : [10, 10, 10]


#Kd_joint          : [1.5, 1.5, 1.5]
#Kp_joint          : [15, 15, 15]

Kp_body           : [100, 100, 100] # 提高刚度以增强稳定性（温和版）
Kd_body           : [10,  10,  10]

Kp_foot           : [500, 500, 500]
Kd_foot           : [10,  10,  10]

#Kp_foot           : [200, 200, 200]
#Kd_foot           : [20, 20, 20]

Kp_ori            : [100, 100, 100] # 提高姿态刚度，减少晃动（温和版）
Kd_ori            : [10,  10,  10]

cmpc_gait         : 9
cmpc_x_drag       : 3
cmpc_use_sparse   : 0
cmpc_bonus_swing  : 0
jcqp_alpha        : 1.5
jcqp_max_iter     : 10000
jcqp_rho          : 1e-07
jcqp_sigma        : 1e-08
jcqp_terminate    : 0.1
use_jcqp          : 0
use_wbc           : 1

# Swing leg parameters
Swing_Kp_cartesian : [350, 350, 150]
Swing_Kd_cartesian : [5.5, 5.5, 5.5]
Swing_Kp_joint     : [0, 0, 0]
Swing_Kd_joint     : [0.2, 0.2, 0.2]
Swing_step_offset  : [0,0.05,-0.003]
Swing_traj_height  : 0.10
Swing_use_tau_ff   : 0

# Two Leg Stance parameters
Q_pos             : [20, 20, 20000]
Q_vel             : [0, 0, 0]
Q_ori             : [1500, 1900, 900]
Q_ang             : [30, 40, 10]

R_control         : 1.1
R_prev            : 2.0

two_leg_orient    : [0.225, 9.1, 0.0]
stance_legs       : 4

# RPC parameters
RPC_Q_p             : [10000, 10000, 100000]
RPC_Q_theta         : [5000, 10000, 2500]
RPC_Q_dp            : [2500, 2500, 500]
RPC_Q_dtheta        : [2.5, 2.5, 50]
RPC_R_r             : [350000, 350000, 350000]
RPC_R_f             : [0.001, 0.001, 0.001]
RPC_H_r_trans       : [1, 2, 1]
RPC_H_r_rot         : [1, 1, 0]
RPC_H_theta0        : [1.25, 0, 0]
RPC_H_phi0          : [-0.3, 0.02, 0]
RPC_mass            : 9
RPC_inertia         : [0.07, 0.26, 0.242]
RPC_gravity         : [0, 0, -9.81]
RPC_mu              : 0.3 # 降低摩擦系数，减少侧向力请求，防止劈叉打滑
RPC_filter          : [0.5, 0.1, 0]
RPC_use_pred_comp   : 1
RPC_use_async_filt  : 1
RPC_visualize_pred  : 1
RPC_use_separate    : 1

# Desired state commands
des_p             : [0,0,0.26]
des_theta         : [0,0,0]
des_dp            : [0,0,0]
des_dtheta        : [0,0,0]
des_theta_max     : [0,0.4,0]
des_dp_max        : [1.0,0.5,0]
des_dtheta_max    : [0,0,3]

# Gait parameters
gait_type             : 4
gait_period_time      : 0.5
gait_switching_phase  : 0.5
gait_override         : 4
gait_max_leg_angle    : 15
gait_max_stance_time  : 0.25
gait_min_stance_time  : 0.1

foot_x_offset_0       : 0
foot_x_offset_1       : 0
foot_x_offset_2       : 0
foot_x_offset_3       : 0
foot_y_offset_0       : 0
foot_y_offset_1       : 0
foot_y_offset_2       : 0
foot_y_offset_3       : 0
foot_z_offset_0       : 0
foot_z_offset_1       : 0
foot_z_offset_2       : 0
foot_z_offset_3       : 0

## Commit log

2025-09-24 Init project
    [3_BODY.SLDPRT, 5887_1.SLDPRT, BOM.xlsx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]
2026-02-25 增加spine
    [c3_body.obj, c3_lower_link.obj, c3_upper_link.obj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]

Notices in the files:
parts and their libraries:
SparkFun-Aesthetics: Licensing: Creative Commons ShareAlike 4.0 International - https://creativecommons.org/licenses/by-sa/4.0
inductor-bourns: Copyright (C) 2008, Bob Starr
